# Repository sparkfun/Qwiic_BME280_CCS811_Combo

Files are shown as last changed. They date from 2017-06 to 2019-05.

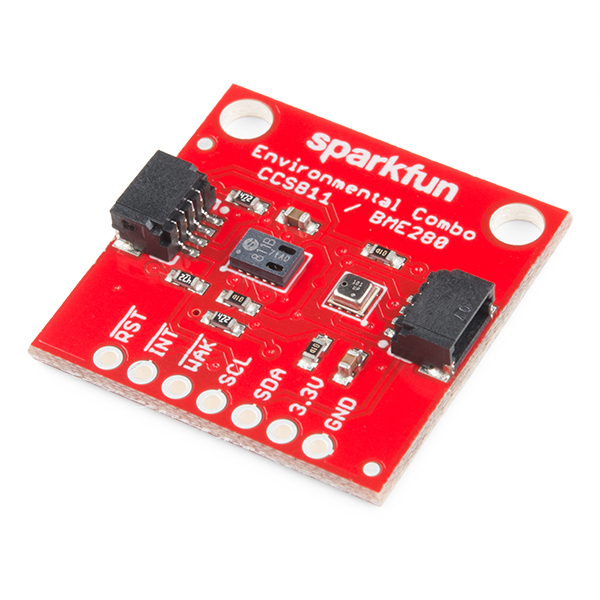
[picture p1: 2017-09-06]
Documentation/readme_picture.jpg

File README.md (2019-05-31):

SparkFun CCS811/BME280 Combo Board
========================================

Sparkfun CCS811/BME280 Combo Board

[*Sparkfun Environmental Combo Breakout CCS811/BME280 (SEN-14348)*](https://www.sparkfun.com/products/14348)

The SparkFun CCS811/BME280 Combo Breakout is perfect for sensing anything you may want to know about the air quality. This breakout will fine tune eCO<sub>2</sub> and tVOC readings from the CCS811 using humidity and temperature readings from the BME280. The breakout will also detect barometric pressure.

Repository Contents
-------------------

* **/Documentation** - Data sheets, additional product information
* **/Firmware** - Example code 
* **/Hardware** - Eagle design files (.brd, .sch)
* **/Libraries** - Libraries for use with the <CCS811/BME280>
* **/Production** - Production panel files (.brd)
* **/Software** - Related software for the <CCS811/BME280>

Documentation
--------------
* **[Library](https://github.com/sparkfun/SparkFun_CCS811_Arduino_Library/)** - <Arduino> library for the CCS811.
* **[Library](https://github.com/sparkfun/SparkFun_BME280_Arduino_Library/)** - <Arduino> library for the BME280.
* **[Hookup Guide](https://learn.sparkfun.com/tutorials/ccs811bme280-qwiic-environmental-combo-breakout-hookup-guide)** - Basic hookup guide for the CCS811/BME280.
* **[SparkFun Fritzing repo](https://github.com/sparkfun/Fritzing_Parts)** - Fritzing diagrams for SparkFun products.
* **[SparkFun 3D Model repo](https://github.com/sparkfun/3D_Models)** - 3D models of SparkFun products. 
* **[SparkFun Graphical Datasheets](https://github.com/sparkfun/Graphical_Datasheets)** -Graphical Datasheets for various SparkFun products.

Product Versions
----------------
* [SEN-14348](https://www.sparkfun.com/products/14348)- Breakout board for the CCS811 and BME 280 air quality sensors.

Version History
---------------
* [CCS811 - V 1.0.0](https://github.com/sparkfun/CCS811_Air_Quality_Breakout/tree/V_1.0.0) - Initial commit of Arduino compatible library for CCS811 
* [BME280 - V 1.0.0](https://github.com/sparkfun/SparkFun_BME280_Arduino_Library/tree/V_1.0.0) - Initial commit of Arduino compatible library for BME280
* [BME280 - V 1.1.0](https://github.com/sparkfun/SparkFun_BME280_Arduino_Library/tree/V_1.1.0) - Pulled request to add decimal precision to readFloatPressure() and readFloatHumidity().

License Information
-------------------

This product is _**open source**_! 

Please review the LICENSE.md file for license information. 

If you have any questions or concerns on licensing, please contact techsupport@sparkfun.com.

Distributed as-is; no warranty is given.

- Your friends at SparkFun.

_<COLLABORATION CREDIT>_

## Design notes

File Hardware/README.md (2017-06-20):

SparkFun <PRODUCT NAME> Design Files
=====================================

The .sch and .brd files hare are Eagle CAD schematic and PCB design files from SparkFun Electronics.
A freeware version of Eagle can be found [here](http://www.cadsoftusa.com/download-eagle/freeware/).

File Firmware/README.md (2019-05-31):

SparkFun CCS811/BME280 Qwiic Environmental Combo Breakout Firmware
===================================

* **Examples** - Arduino examples used in the Environmental Combo Hookup Guide

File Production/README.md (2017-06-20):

SparkFun <PRODUCT NAME> Production Files
=========================================

These are the production files SparkFun uses for printing PCBs.

License Information
-------------------
This product is open source! 

The hardware is released under [Creative Commons ShareAlike 4.0 International](https://creativecommons.org/licenses/by-sa/4.0/).

Please use, reuse, and modify these files as you see fit. Please maintain attribution to SparkFun Electronics and release anything derivative under the same license.

Distributed as-is; no warranty is given.

- Your friends at SparkFun.

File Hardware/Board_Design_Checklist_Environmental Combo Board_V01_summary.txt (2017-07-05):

1) Do all VCC connections use the VCC symbol (oriented upward)? [NO]
comment: 3.3V instead of VCC, should probably stay this way?

2) Do all testpoints have a separation of at least 0.1 inch (preferably placed on a 0.05 inch grid)? [n/a]
comment: no test points? I2C connectors for test

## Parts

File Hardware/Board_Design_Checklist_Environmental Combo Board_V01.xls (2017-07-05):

SECTION | CHECK | STATUS | DEPENDANCY | CORRECT ANSWER | USER | USER-ANSWER | COMMENT | WIKI_LINK
Macro | is_revision | 1
Macro | has_pth | 1
Macro | has_i2c | 1
Macro | has_SPI | 0
Macro | has_1x6_ftdi_header | 0
Macro | has_jumpers | 0
Macro | has_leds | 0
Macro | has_vreg | 0
Macro | has_QFN | 0
Macro | has_SS | 0
Macro | has_multi_sheet | 0
Macro | is_kit | 0
Macro | has_serial | 0
Macro | is_4layer | 0
Macro | has_milling | 0
Macro | has_switchorbutton | 0
General | Are the part libraries consistent with eagle github repo? |  |  | YES | andrew.england | YES
Schematic | Is the proper frame with CC attribution used? |  |  | YES | andrew.england | YES
Schematic | Are all schematic objects inside the frame? |  |  | YES | andrew.england | YES
Schematic | Is there a SparkFun Logo? |  |  | YES | andrew.england | YES
Schematic | Is there an OSHW logo? |  |  | YES | andrew.england | YES
Schematic | Is proper attribution given to the original designer? |  |  | YES | andrew.england | YES
Schematic | Is "Revised by: " and the reviser's name present? |  | 2 | YES | andrew.england | YES
Schematic | Are NET labels the correct FLAG type? |  |  | YES | andrew.england | YES
Schematic | Have all nets been drawn straight out from pin connections at least one grid space? |  |  | YES | andrew.england | YES
Schematic | Are all net lines 0.006 inch? |  |  | YES | andrew.england | YES
Schematic | Are there any 4-way junctions? |  |  | NO | andrew.england | NO
Schematic | Are junction dots used for all 3-wire connections? |  |  | YES | andrew.england | YES
Schematic | Are the fiducials in the lower right corner? |  |  | YES | andrew.england | YES
Schematic | Are the standoffs in the lower right corner? |  |  | YES | andrew.england | YES
Schematic | Are dashed grey lines ('info' eagle layer 97) used to clearly separate different areas? |  |  | YES | andrew.england | YES
Schematic | Is the version number correct? |  |  | YES | andrew.england | YES
Schematic | Is the version number included on all sheets? |  | 12 | YES | andrew.england | *n/a*
Schematic | Do all GND connections use the GND symbol (oriented downward)? |  |  | YES | andrew.england | YES
Schematic | Do all VCC connections use the VCC symbol (oriented upward)? |  |  | YES | andrew.england | NO | 3.3V instead of VCC, should probably stay this way?
Schematic | Is the VCC range clearly labeled? |  |  | YES | andrew.england | YES
Schematic | Are any jumpers labeled clearly by their function and possible settings? |  | 7 | YES | andrew.england | *n/a*
Schematic | Are any appropriate warnings (voltage conversion, sensitive I/O) labeled? |  |  | YES | andrew.england | YES
Schematic | Are any notes of two versions of the board in the schematic (3.3V regulator vs 5V regulator)? |  |  | YES | andrew.england | n/a
Schematic | Do any part names have '/.~' in them? (Multiple sheets) |  | 12 | NO | andrew.england | *n/a*
Schematic | Have you verified that the BOM in Sparkle is accurate (also checking for PROD_ID, NAME, VALUE, PREFIX)? |  |  | YES | andrew.england | YES
Schematic | Do any parts have unnecessary values (Eagle has autoset the package as the value)? |  |  | NO | andrew.england | NO
Schematic | Regarding the voltage regulator, is the input on the LEFT, and the output on the RIGHT? |  | 9 | YES | andrew.england | *n/a*
Schematic | Is the I2C address in the schematic? |  | 4 | YES | andrew.england | YES
Schematic | Is it the standard I2C pin order used (GND/VCC/SDA/CLK)? |  | 4 | YES | andrew.england | YES |  | http://wiki.internal.sparkfun.com/index.php?title=Eagle_Rules#Pin_Out.2FConnection_Orientation
Schematic | Is the I2C pull-up resistor isolation jumper present? |  | 4 | YES | andrew.england | YES |  | http://wiki.internal.sparkfun.com/index.php?title=Eagle_Rules#Component_Placement
Schematic | Is the SPI pull-up resistor for Chip Select present? |  | 5 | YES | andrew.england | *n/a* |  | http://wiki.internal.sparkfun.com/index.php?title=Eagle_Rules#Component_Placement
Schematic | Is the MISO tri-state buffer included? |  | 5 | YES | andrew.england | *n/a* |  | http://wiki.internal.sparkfun.com/index.php?title=Eagle_Rules#Component_Placement
Board | Are the inner layers on the correct eagle layers? (2 and 15) |  | 15 | YES | andrew.england | *n/a* |  | http://wiki.internal.sparkfun.com/index.php?title=Eagle_Rules#Board_Creation.2C_Outline
Board | Does your 4 layer board include '1' '2' '3' '4' in the copper of each layer? |  | 15 | YES | andrew.england | *n/a* |  | http://wiki.internal.sparkfun.com/index.php?title=Eagle_Rules#Board_Creation.2C_Outline
Board | Is the bottom left corner board dimensions at 0,0? |  |  | YES | andrew.england | YES |  | http://wiki.internal.sparkfun.com/index.php?title=Eagle_Rules#Board_Creation.2C_Outline
Board | Is the board dimension outline correct thickness? (0.008 inch) |  |  | YES | andrew.england | YES |  | http://wiki.internal.sparkfun.com/index.php?title=Eagle_Rules#Board_Creation.2C_Outline
Board | If this requires very precise dimensions (e.g. USB stick), did you consider GP's tolerances? (dimension=5mils, Vscore=10mils) |  |  |  | andrew.england | YES |  | http://wiki.internal.sparkfun.com/index.php?title=Eagle_Rules#Fab_house_Tolerances
Board | Are 0.1 inch headers lined up on 0.1 inch grid? |  |  | YES | andrew.england | YES |  | http://wiki.internal.sparkfun.com/index.php?title=Eagle_Rules#Board_Creation.2C_Outline
Board | Are opposing 0.1 inch headers spaced to fit into a breadboard? |  |  | YES | andrew.england | n/a |  | http://wiki.internal.sparkfun.com/index.php?title=Eagle_Rules#Board_Creation.2C_Outline
Board | Do all testpoints have a separation of at least 0.1 inch (preferably placed on a 0.05 inch grid)? |  |  | YES | andrew.england | n/a | no test points? I2C connectors for test | http://wiki.internal.sparkfun.com/index.php?title=Eagle_Rules#Board_Creation.2C_Outline
Board | Does the board have standoffs? |  |  | YES | andrew.england | YES |  | http://wiki.internal.sparkfun.com/index.php?title=Eagle_Rules#Board_Creation.2C_Outline
Board | Can standoffs/screws be used clear of other parts? |  |  | YES | andrew.england | YES |  | http://wiki.internal.sparkfun.com/index.php?title=Eagle_Rules#Board_Creation.2C_Outline
Board | Is the FTDI connector accessible (do neighboring parts allow enough space to clear each side)? |  | 6 | YES | andrew.england | *n/a* |  | http://wiki.internal.sparkfun.com/index.php?title=Eagle_Rules#Pin_Out.2FConnection_Orientation
Board | Is the FTDI connector oriented so the FTDI breakout can be slid on properly (IC side up, header side down)? |  | 6 | YES | andrew.england | *n/a* |  | http://wiki.internal.sparkfun.com/index.php?title=Eagle_Rules#Pin_Out.2FConnection_Orientation
Board | Are vias tented correctly? |  |  | YES | andrew.england | YES |  | http://wiki.internal.sparkfun.com/index.php?title=Eagle_Rules
Board | If possible, are all overhanging parts on the same edge of the board (this helps with panelization)? |  |  | YES | andrew.england | YES |  | http://wiki.internal.sparkfun.com/index.php?title=Eagle_Rules#Pin_Out.2FConnection_Orientation
Board | Does this board adhere to the standard manufacturing process? (Kitting time, glue curing, humidor time, etc.) |  |  | YES | andrew.england | YES
Board | Are any vias intended to be used as PTH headers (they shouldn't be)? |  |  | NO | andrew.england | NO |  | http://wiki.internal.sparkfun.com/index.php?title=Eagle_Rules
Board | Is the LED color standard followed? (red for power, blue for STAT, green for TX, yellow for RX) |  | 8 | YES | andrew.england | *n/a* |  | http://wiki.internal.sparkfun.com/index.php?title=Eagle_Rules#Component_Placement
Board | Are all PTH parts selective solder compatible? (same side, plenty of clearance around pins) |  | 11 | YES | andrew.england | *n/a* |  | http://wiki.internal.sparkfun.com/index.php?title=Eagle_Rules#Pin_Out.2FConnection_Orientation
Board | As best as possible, do all SMD pads have only 1 trace entering the pad? |  |  | YES | andrew.england | YES |  | http://wiki.internal.sparkfun.com/index.php?title=Eagle_Rules#PCB_Layout
Board | Are there any natural bridges on SMT components? |  |  | NO | andrew.england | YES |  | http://wiki.internal.sparkfun.com/index.php?title=Eagle_Rules#PCB_Layout
Board | Do V-Scored edges have a 50 mil border free of pads and parts (to prevent cracking on separation)? |  |  | YES | andrew.england | n/a
Board | Is the direction of TX/RX serial connections correct? |  | 14 | YES | andrew.england | *n/a*
Board | Are the TX/RX pins of the FTDI properly connected? |  | 6 | YES | andrew.england | *n/a*
Board | Is trace routing up to spec? (to/from center-points, straight lines, 45 angles, 'T' intersections, no right angles or acid traps) |  |  | YES | andrew.england | YES |  | http://wiki.internal.sparkfun.com/index.php?title=Eagle_Rules#PCB_Layout
Board | For thermal considerations, are traces routed away from the component, with symmetrical routing? |  | 10 | YES | andrew.england | *n/a*
Board | Do all footprints pass 1:1 check? (Applies mostly to new components) |  |  | YES | andrew.england | YES
Board | Are all QFN components with 6 or more leads 75 percent pasted on lead pads? (May be contended depending on performance) |  | 10 | YES | andrew.england | *n/a* |  | http://wiki.internal.sparkfun.com/index.php?title=Eagle_Rules#Footprints.2FPackages
Board | Are center pad cream apertures properly reduced? (50-75% paste is good) |  | 10 | YES | andrew.england | *n/a* |  | http://wiki.internal.sparkfun.com/index.php?title=Eagle_Rules#Footprints.2FPackages
Board | Is there solder mask between pads on of 11 mil separation and greater? |  |  | YES | andrew.england | YES |  | http://wiki.internal.sparkfun.com/index.php?title=Eagle_Rules#Fab_house_Tolerances
Board | Is there a correct version number in the copper (aligned properly with the edge of the PCB)? |  |  | YES | andrew.england | YES
Board | Are there fiducials on both the TOP and BOTTOM of the board? |  |  | YES | andrew.england | YES
Board | Does it pass DRC with top/bottom keepout layers on? |  |  | YES | andrew.england | YES
Board | If there are any DRC errors, have they all been approved? |  |  | YES | andrew.england | YES
Board | Are there airwires after ratsnest? |  |  | NO | andrew.england | NO
Board | Are all KIT PTH parts on the correct side with correct masking (e.g. the TSTOP or BSTOP expose the correct side) |  | 13 | YES | andrew.england | *n/a*
Documentation | Is there a note for a 4-layer board (on tDOCU)? |  | 15 | YES | andrew.england | *n/a*
Documentation | Do all packages have NAME and VALUE? |  |  | YES | andrew.england | YES
Documentation | Is there a note for a board thickness other than 0.63 inch? |  |  |  | andrew.england | NO
Documentation | Are measurements included for outer dimension and standoffs (Eagle layer 47)? |  |  | YES | andrew.england | YES
Documentation | Are the board dimensions on 0.05 inch or 0.01 inch grid? |  |  | YES | andrew.england | YES
Documentation | Are routed-out areas labeled 'ROUTE OUT' (on dimension)? |  | 16 | YES | andrew.england | *n/a*
Documentation | Is the CC/Design By included in tDocu? |  |  | YES | andrew.england | YES
Documentation | Is the designer name included in tDocu? |  |  | YES | andrew.england | YES
Documentation | Is 'Revised by:' and 'Revisor Name' included in tDocu? |  | 2 | YES | andrew.england | YES
Silkscreen/Labeling | Is the name of the board on the board? |  |  | YES | andrew.england | YES |  | http://wiki.internal.sparkfun.com/index.php?title=Eagle_Rules#PCB_Silk
Silkscreen/Labeling | Do all footprints have 0.008 inch silk footprint? |  |  | YES
Silkscreen/Labeling | Are all LEDs labeled with their purpose? |  | 8 | YES
Silkscreen/Labeling | Are all PTHs (aka connectors) clearly labeled with their purpose on both sides of the board? |  |  | YES | andrew.england | YES
Silkscreen/Labeling | Are battery terminals labeled +/- correctly? |  |  | YES | andrew.england | YES
Silkscreen/Labeling | Are all jumpers labeled? |  | 7 | YES | andrew.england | *n/a*
Silkscreen/Labeling | If it is a 3-way jumper, is there a label on each side of the jumper? |  | 7 | YES | andrew.england | *n/a*
Silkscreen/Labeling | Are all switches/buttons labeled properly? |  | 17 | YES | andrew.england | *n/a*
Silkscreen/Labeling | Are active low pins labeled clearly? |  |  | YES | andrew.england | YES
Silkscreen/Labeling | Are all labels lined up properly? |  |  | YES | andrew.england | YES
Silkscreen/Labeling | Is all text at least 0.032 inch, 15 percent radio, and vector? |  |  | YES | andrew.england | YES
Silkscreen/Labeling | Does the FTDI connector have BLK/GRN labeled correctly? |  | 6 | YES | andrew.england | *n/a*
Silkscreen/Labeling | Do all components have polarity or pin 1 labeled? |  |  | YES | andrew.england | YES
Silkscreen/Labeling | Is the polarity label outside of the package for visibility after part population? |  |  | YES | andrew.england | YES
Silkscreen/Labeling | Are there check labels for different versions of the board (3.3V vs 5V)? |  |  | YES | andrew.england | n/a
Silkscreen/Labeling | Is the SparkFun Logo on the board? |  |  | YES | andrew.england | YES
Silkscreen/Labeling | Is the OSHW logo on the board? |  |  | YES | andrew.england | YES
Silkscreen/Labeling | Is any silkscreen overlaid on vias? |  |  | NO | andrew.england | YES
Silkscreen/Labeling | Is there a URL for any kits or unique boards? |  |  |  | andrew.england | NO
Special | Are dimension lines properly spaced for V-scoring (lines on a 0.020” center-to-center spacing)? |  |  |  | andrew.england | n/a
Special | On white solder mask pcbs, is there any solder mask between leads on large SMT components? |  |  |  | andrew.england | n/a
Special | Are axes labeled correctly? |  |  |  | andrew.england | n/a
Special | Are there warning labels for high voltage areas? |  |  |  | andrew.england | n/a
END | Thanks for flying with us. Have a great day!! |  |  |  | andrew.england | n/a

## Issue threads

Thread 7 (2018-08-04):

I2C_Error with Wemos D1 R2

Coderkido, 2018-08-04:
Hi,
Using libraries was working with an Uno, using the module on Wemos is returning I2C Errors for the CCS and same for BME280.

Both devices are discovered with an I2C Scan.

https://gist.github.com/Coderkido/1b58b96edec79937f611ece7d0b867c8

Is a gist of what I'm doing.

Coderkido, 2018-08-04:
I2C Scan SOMETIMES find the devices.

Otherwise returns:

`Unknow error at address 0x69
Unknow error at addr
Soft WDT reset

ctx: cont
sp: 3ffef7a0 end: 3ffef9f0 offset: 01b0

>>>stack>>>
3ffef950:  feefeffe 00000001 3ffe88e6 40202d54
3ffef960:  00000000 00000014 3ffe88c2 40202d54
3ffef970:  0000006a 00000002 3ffee99c 3ffee748
3ffef980:  00000000 0000006a 3ffee99c 402028b5
3ffef990:  3ffe88ae 0000006a 3ffee759 402026a8
3ffef9a0:  3ffe8870 00000001 3ffee99c 402028c8
3ffef9b0:  00002580 00000069 3ffee99c 40202480
3ffef9c0:  feefeffe 00000000 3ffee99c 3ffee9c0
3ffef9d0:  3fffdad0 00000000 3ffee9b8 40202b74
3ffef9e0:  feefeffe feefeffe 3ffee9d0 40100108
<<<stack<<<
⸮⸮⸮⸮(⸮⸮
y⸮
I2C Scanner
Scanning...
`

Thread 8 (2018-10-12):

code replicates error in vendor documentation

pabigot, 2018-10-12:
Around [here](https://github.com/sparkfun/Qwiic_BME280_CCS811_Combo/blob/3e43b3289bce05ccb271034105f0ce0e1a6ca11d/Libraries/CCS811/src/SparkFunCCS811.cpp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) the code for configuring the CCS811 ENV_DATA values faithfully represents the instructions in the [CCS811 Programming guide](https://ams.com/documents/20143/36005/CCS811_AN000369_2-00.pdf/25d0db9a-92b9-fa7f-362c-a7a4d1e292be) section 16, being:
```
i2c_buff[0] = ((RH % 1000) / 100) > 7 ? (RH/1000 + 1)<<1 : (RH/1000)<<1;
i2c_buff[1] = 0;
if(((RH % 1000) / 100) > 2 && (((RH % 1000) / 100) < 8)) {
  i2c_buff[0] |= 1;
}
```
The demonstration code is wrong, as it results in storing a value that is one unit too large when the fractional part is strictly between 0.7 and 0.8.  In that case the whole value is incremented and the half-value is added, applying the half-round operation twice.

I don't use this library, but found this while trying to figure out why writing `ENV_DATA` doesn't work on my board (the I2C read of address 0x05 sets `READ_REG_INVALID` in `ERROR_ID`), and figured somebody might find this useful.

nseidle, 2018-10-12:
I think I get what you're saying.

Let's run 42.745 through the code.

    envData[0] = ((rH % 1000) / 100) > 7 ? (rH / 1000 + 1) << 1 : (rH / 1000) << 1;

This puts (42<<1) in envData[0]. Then

    if (((rH % 1000) / 100) > 2 && (((rH % 1000) / 100) < 8))
        envData[0] |= 1; //Set 9th bit of fractional to indicate 0.5%

This puts the 0.5 into bit 0. So the outcome is 42.5%. Looks good.

Let's run 42.856 through.

    envData[0] = ((rH % 1000) / 100) > 7 ? (rH / 1000 + 1) << 1 : (rH / 1000) << 1;

This puts (43<<1) in envData[0]. Then

    if (((rH % 1000) / 100) > 2 && (((rH % 1000) / 100) < 8))
        envData[0] |= 1; //Set 9th bit of fractional to indicate 0.5%

This puts the 0.5 into bit 0. So the outcome is 43.5%. That's too much.

So I think the solution is:

    envData[1] = 0; //CCS811 only supports increments of 0.5 so bits 7-0 will always be zero

    //Split value into 7-bit integer and 9-bit fractional
    if( (rH % 1000) / 100 > 7)
    {
      envData[0] = (rH / 1000 + 1) << 1; //Increase 42.756 to 43.0
    }
    else
    {
      envData[0] = (rH / 1000) << 1; //Store 42
      if ( (rH % 1000) / 100 > 2)
        envData[0] |= 1; //Set 9th bit of fractional to indicate 0.5% - 42.5%
    }

pabigot, 2018-10-12:
Yeah, you could do something like that.  Or just rely on integer truncation and do:
```
envData[0] = (rH + 250) / 500;
```
which rounds to the nearest half unit.

nseidle, 2018-10-12:
Much sneakier. Thanks - updating lib.

pabigot, 2018-10-12:
You're welcome.

If anybody else gets here because attempting to read the `ENV_DATA` register fails, my conclusion is that the register is not readable: it fails with both app firmware 1.1.0 (which was on the Sparkfun board I got long ago), and with 2.0.0.  Which is pretty annoying, since I'd like to know whether the power-on state has sane defaults (see NordicSemiconductor/Nordic-Thingy52-FW#21 for background).

Also, initial experience with 2.0.0 appears to fix a variety of issues with the status, and maybe baseline maintenance.

hmhalvorsen, 2018-12-17:
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

I am not sure if this is correct. ((42856 mod 1000) / 100) = 8.56, which is not less than 8. Surely we wouldn't set the 9th bit here?

hmhalvorsen, 2018-12-17:
Yes, that makes sense. Thank you for clarifying this matter.

fbraswell, 2019-06-18:
Why to go all the trouble of the code in the data sheet, which tries to keep the 8 bits of fraction zero? The direct way to populate the two %RH registers is to multiply the RH value by 512, convert the value to an int and split it in two. Here's the code in the Squirrel language for the Electric Imp processor:

        // The 16 bit %RH register is composed of a 7 bit integer portion and 9 bit
        // fractional portion. Multiplying the %RH by 512 effectively populates the
        // integer and fractional portion.
        local h = hval * 512;
        // Next, split the two bytes of the integer apart for sending to the ENV_DATA registers
        local h_hi = h.tointeger() >> 8; // get upper 8 bits
        local h_lo = h.tointeger() & 0x00FF; // grab lower 8 bits

The temperature calculation adds the 25 degree offset:

        // First, convert the tempF to tempC
        local tvalC = (tvalF - 32.0) * 5.0 / 9.0;
        // In this case, there is an offset of 25 deg C. This means that if the 2 registers are 0
        // then the temperature is -25 deg C
        // For the computation, add the offset of 25 and multiply by 512, as we did with the %RH above
        local t = (tvalC + 25.0) * 512;
        // Split the integer into two parts for sending the the ENV_DATA registers
        local t_hi = t.tointeger() >> 8; // get upper 8 bits
        local t_lo = h.tointeger() & 0x00FF; // grab lower 8 bits

532910, 2019-07-20:
[CCS811 datasheet](https://ams.com/documents/20143/36005/CCS811_DS000459_7-00.pdf/3cfdaea5-b602-fe28-1a14-18776b61a35a) says:
> Temperature / Humidity is stored as an unsigned 16 bits in 1/512

Could you explain, why

> bits 7-0 will always be zero

?

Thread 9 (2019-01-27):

Example for combined reading on Raspberry Pi?

syr, 2019-01-27:
I'm a bloody beginner. So it would be helpful to see in an example
how to do combined readings with python which can be executed on a raspberry pi. :)
Any chance?

nseidle, 2019-01-30:
We'd welcome a PR on either of the sensor libraries ([CCS811](https://github.com/sparkfun/SparkFun_CCS811_Arduino_Library/) or [BME280](https://github.com/sparkfun/SparkFun_BME280_Arduino_Library/)) from anyone who want to contribute but most of our support is for Arduino instead of RPi/python.

Closed 2019-01-30.

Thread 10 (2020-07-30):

Examples won't compile

cmfrancis, 2020-07-30:
Last line of the error received is:
variable or field 'printDriverError' declared void

crampaldo, 2020-09-18:
I am having the same error

JustMakeStuff-tech, 2020-10-09:
I am having that same error as well

JustMakeStuff-tech, 2020-10-09:
I just proposed some changes where the "variable or field 'printDriverError' declared void" error is fixed

JustMakeStuff-tech, 2023-05-11:
See [https://github.com/sparkfun/Qwiic_BME280_CCS811_Combo/commit/b0c013b651c99ae166d396f3a4776d240a9861f1](this).

JialongWang1201, 2023-05-11:
> See [this](https://github.com/sparkfun/Qwiic_BME280_CCS811_Combo/commit/b0c013b651c99ae166d396f3a4776d240a9861f1).

/private/var/folders/rj/1zgtr70j3lb03hztfp7t7tlc0000gn/T/.arduinoIDE-unsaved2023411-27445-w42zu.6hw5w/sketch_may11a/sketch_may11a.ino:22:12: error: stray '@' in program
 Expand All @@ -67,11 +67,11 @@ void setup()
            ^
/private/var/folders/rj/1zgtr70j3lb03hztfp7t7tlc0000gn/T/.arduinoIDE-unsaved2023411-27445-w42zu.6hw5w/sketch_may11a/sketch_may11a.ino:22:13: error: stray '@' in program
 Expand All @@ -67,11 +67,11 @@ void setup()
             ^
/private/var/folders/rj/1zgtr70j3lb03hztfp7t7tlc0000gn/T/.arduinoIDE-unsaved2023411-27445-w42zu.6hw5w/sketch_may11a/sketch_may11a.ino:22:29: error: stray '@' in program
 Expand All @@ -67,11 +67,11 @@ void setup()
                             ^
/private/var/folders/rj/1zgtr70j3lb03hztfp7t7tlc0000gn/T/.arduinoIDE-unsaved2023411-27445-w42zu.6hw5w/sketch_may11a/sketch_may11a.ino:22:30: error: stray '@' in program
 Expand All @@ -67,11 +67,11 @@ void setup()
                              ^
/private/var/folders/rj/1zgtr70j3lb03hztfp7t7tlc0000gn/T/.arduinoIDE-unsaved2023411-27445-w42zu.6hw5w/sketch_may11a/sketch_may11a.ino:34:12: error: stray '@' in program
 Expand All @@ -90,18 +90,18 @@ void loop()
            ^
/private/var/folders/rj/1zgtr70j3lb03hztfp7t7tlc0000gn/T/.arduinoIDE-unsaved2023411-27445-w42zu.6hw5w/sketch_may11a/sketch_may11a.ino:34:13: error: stray '@' in program
 Expand All @@ -90,18 +90,18 @@ void loop()
             ^
/private/var/folders/rj/1zgtr70j3lb03hztfp7t7tlc0000gn/T/.arduinoIDE-unsaved2023411-27445-w42zu.6hw5w/sketch_may11a/sketch_may11a.ino:34:29: error: stray '@' in program
 Expand All @@ -90,18 +90,18 @@ void loop()
                             ^
/private/var/folders/rj/1zgtr70j3lb03hztfp7t7tlc0000gn/T/.arduinoIDE-unsaved2023411-27445-w42zu.6hw5w/sketch_may11a/sketch_may11a.ino:34:30: error: stray '@' in program
 Expand All @@ -90,18 +90,18 @@ void loop()
                              ^
/private/var/folders/rj/1zgtr70j3lb03hztfp7t7tlc0000gn/T/.arduinoIDE-unsaved2023411-27445-w42zu.6hw5w/sketch_may11a/sketch_may11a.ino:53:12: error: stray '@' in program
 Expand All @@ -110,70 +110,71 @@ void loop()
            ^
/private/var/folders/rj/1zgtr70j3lb03hztfp7t7tlc0000gn/T/.arduinoIDE-unsaved2023411-27445-w42zu.6hw5w/sketch_may11a/sketch_may11a.ino:53:13: error: stray '@' in program
 Expand All @@ -110,70 +110,71 @@ void loop()
             ^
/private/var/folders/rj/1zgtr70j3lb03hztfp7t7tlc0000gn/T/.arduinoIDE-unsaved2023411-27445-w42zu.6hw5w/sketch_may11a/sketch_may11a.ino:53:31: error: stray '@' in program
 Expand All @@ -110,70 +110,71 @@ void loop()
                               ^
/private/var/folders/rj/1zgtr70j3lb03hztfp7t7tlc0000gn/T/.arduinoIDE-unsaved2023411-27445-w42zu.6hw5w/sketch_may11a/sketch_may11a.ino:53:32: error: stray '@' in program
 Expand All @@ -110,70 +110,71 @@ void loop()
                                ^
/private/var/folders/rj/1zgtr70j3lb03hztfp7t7tlc0000gn/T/.arduinoIDE-unsaved2023411-27445-w42zu.6hw5w/sketch_may11a/sketch_may11a.ino:101:24: error: variable or field 'printDriverError' declared void
  void printDriverError( CCS811Core::CCS811_Status_e errorCode )
                        ^~~~~~~~~~
/private/var/folders/rj/1zgtr70j3lb03hztfp7t7tlc0000gn/T/.arduinoIDE-unsaved2023411-27445-w42zu.6hw5w/sketch_may11a/sketch_may11a.ino:101:24: error: 'CCS811Core' has not been declared
/private/var/folders/rj/1zgtr70j3lb03hztfp7t7tlc0000gn/T/.arduinoIDE-unsaved2023411-27445-w42zu.6hw5w/sketch_may11a/sketch_may11a.ino: In function 'void setup()':
/private/var/folders/rj/1zgtr70j3lb03hztfp7t7tlc0000gn/T/.arduinoIDE-unsaved2023411-27445-w42zu.6hw5w/sketch_may11a/sketch_may11a.ino:7:4: error: 'Wire' was not declared in this scope
    Wire.begin();//initialize I2C bus
    ^~~~
/private/var/folders/rj/1zgtr70j3lb03hztfp7t7tlc0000gn/T/.arduinoIDE-unsaved2023411-27445-w42zu.6hw5w/sketch_may11a/sketch_may11a.ino:10:4: error: 'CCS811Core' has not been declared
    CCS811Core::CCS811_Status_e returnCode = myCCS811.beginWithStatus ();
    ^~~~~~~~~~
/private/var/folders/rj/1zgtr70j3lb03hztfp7t7tlc0000gn/T/.arduinoIDE-unsaved2023411-27445-w42zu.6hw5w/sketch_may11a/sketch_may11a.ino:11:8: error: 'returnCode' was not declared in this scope
    if (returnCode != CCS811Core::CCS811_Stat_SUCCESS)
        ^~~~~~~~~~
/private/var/folders/rj/1zgtr70j3lb03hztfp7t7tlc0000gn/T/.arduinoIDE-unsaved2023411-27445-w42zu.6hw5w/sketch_may11a/sketch_may11a.ino:11:22: error: 'CCS811Core' has not been declared
    if (returnCode != CCS811Core::CCS811_Stat_SUCCESS)
                      ^~~~~~~~~~
/private/var/folders/rj/1zgtr70j3lb03hztfp7t7tlc0000gn/T/.arduinoIDE-unsaved2023411-27445-w42zu.6hw5w/sketch_may11a/sketch_may11a.ino:14:6: error: 'printDriverError' was not declared in this scope
      printDriverError(returnCode);
      ^~~~~~~~~~~~~~~~
/private/var/folders/rj/1zgtr70j3lb03hztfp7t7tlc0000gn/T/.arduinoIDE-unsaved2023411-27445-w42zu.6hw5w/sketch_may11a/sketch_may11a.ino:22:1: error: 'Expand' was not declared in this scope
 Expand All @@ -67,11 +67,11 @@ void setup()
 ^~~~~~
/private/var/folders/rj/1zgtr70j3lb03hztfp7t7tlc0000gn/T/.arduinoIDE-unsaved2023411-27445-w42zu.6hw5w/sketch_may11a/sketch_may11a.ino:22:1: note: suggested alternative: 'srand'
 Expand All @@ -67,11 +67,11 @@ void setup()
 ^~~~~~
 srand
/private/var/folders/rj/1zgtr70j3lb03hztfp7t7tlc0000gn/T/.arduinoIDE-unsaved2023411-27445-w42zu.6hw5w/sketch_may11a/sketch_may11a.ino:24:8: error: 'id' was not declared in this scope
    if (id != 0x60)
        ^~
/private/var/folders/rj/1zgtr70j3lb03hztfp7t7tlc0000gn/T/.arduinoIDE-unsaved2023411-27445-w42zu.6hw5w/sketch_may11a/sketch_may11a.ino:34:8: error: expected ';' before 'All'
 Expand All @@ -90,18 +90,18 @@ void loop()
        ^~~
/private/var/folders/rj/1zgtr70j3lb03hztfp7t7tlc0000gn/T/.arduinoIDE-unsaved2023411-27445-w42zu.6hw5w/sketch_may11a/sketch_may11a.ino:36:23: error: 'myBME280' was not declared in this scope
      float BMEhumid = myBME280.readFloatHumidity();
                       ^~~~~~~~
/private/var/folders/rj/1zgtr70j3lb03hztfp7t7tlc0000gn/T/.arduinoIDE-unsaved2023411-27445-w42zu.6hw5w/sketch_may11a/sketch_may11a.ino:39:22: error: 'BMEtempC' was not declared in this scope
      SerialUSB.print(BMEtempC);
                      ^~~~~~~~
/private/var/folders/rj/1zgtr70j3lb03hztfp7t7tlc0000gn/T/.arduinoIDE-unsaved2023411-27445-w42zu.6hw5w/sketch_may11a/sketch_may11a.ino:39:22: note: suggested alternative: 'BMEhumid'
      SerialUSB.print(BMEtempC);
                      ^~~~~~~~
                      BMEhumid
/private/var/folders/rj/1zgtr70j3lb03hztfp7t7tlc0000gn/T/.arduinoIDE-unsaved2023411-27445-w42zu.6hw5w/sketch_may11a/sketch_may11a.ino:45:6: error: 'myCCS811' was not declared in this scope
      myCCS811.setEnvironmentalData(BMEhumid, BMEtempC);
      ^~~~~~~~
/private/var/folders/rj/1zgtr70j3lb03hztfp7t7tlc0000gn/T/.arduinoIDE-unsaved2023411-27445-w42zu.6hw5w/sketch_may11a/sketch_may11a.ino: At global scope:
/private/var/folders/rj/1zgtr70j3lb03hztfp7t7tlc0000gn/T/.arduinoIDE-unsaved2023411-27445-w42zu.6hw5w/sketch_may11a/sketch_may11a.ino:47:4: error: expected unqualified-id before 'else'
    else if (myCCS811.checkForStatusError())
    ^~~~
/private/var/folders/rj/1zgtr70j3lb03hztfp7t7tlc0000gn/T/.arduinoIDE-unsaved2023411-27445-w42zu.6hw5w/sketch_may11a/sketch_may11a.ino:52:9: error: expected constructor, destructor, or type conversion before '(' token
    delay(2000); //Wait for next reading
         ^
/private/var/folders/rj/1zgtr70j3lb03hztfp7t7tlc0000gn/T/.arduinoIDE-unsaved2023411-27445-w42zu.6hw5w/sketch_may11a/sketch_may11a.ino:53:1: error: 'Expand' does not name a type; did you mean 'srand'?
 Expand All @@ -110,70 +110,71 @@ void loop()
 ^~~~~~
 srand
/private/var/folders/rj/1zgtr70j3lb03hztfp7t7tlc0000gn/T/.arduinoIDE-unsaved2023411-27445-w42zu.6hw5w/sketch_may11a/sketch_may11a.ino:101:25: error: variable or field 'printDriverError' declared void
  void printDriverError( CCS811Core::CCS811_Status_e errorCode )
                         ^~~~~~~~~~
/private/var/folders/rj/1zgtr70j3lb03hztfp7t7tlc0000gn/T/.arduinoIDE-unsaved2023411-27445-w42zu.6hw5w/sketch_may11a/sketch_may11a.ino:101:25: error: 'CCS811Core' has not been declared

exit status 1

Compilation error: stray '@' in program

JialongWang1201, 2023-05-11:
> See [this](https://github.com/sparkfun/Qwiic_BME280_CCS811_Combo/commit/b0c013b651c99ae166d396f3a4776d240a9861f1).

but I got the new bug

JustMakeStuff-tech, 2023-05-11:
Can I see your code?

JialongWang1201, 2023-05-11:
> Can I see your code?

void setup()
 {
   SerialUSB.begin(9600);
   SerialUSB.println();
   SerialUSB.println("Apply BME280 data to CCS811 for compensation.");

   Wire.begin();//initialize I2C bus

   //This begins the CCS811 sensor and prints error status of .begin()
   CCS811Core::CCS811_Status_e returnCode = myCCS811.beginWithStatus ();
   if (returnCode != CCS811Core::CCS811_Stat_SUCCESS)
   {
     SerialUSB.println("Problem with CCS811");
     printDriverError(returnCode);
   }
   else
   {
     SerialUSB.println("CCS811 online");
   }

Expand All	@@ -67,11 +67,11 @@ void setup()
   byte id = myBME280.begin(); //Returns ID of 0x60 if successful
   if (id != 0x60)
   {
     SerialUSB.println("Problem with BME280");
   }
   else
   {
     SerialUSB.println("BME280 online");
   }

Expand All	@@ -90,18 +90,18 @@ void loop()
     float BMEtempC = myBME280.readTempC();
     float BMEhumid = myBME280.readFloatHumidity();

     SerialUSB.print("Applying new values (deg C, %): ");
     SerialUSB.print(BMEtempC);
     SerialUSB.print(",");
     SerialUSB.println(BMEhumid);
     SerialUSB.println();

     //This sends the temperature data to the CCS811
     myCCS811.setEnvironmentalData(BMEhumid, BMEtempC);
   }
   else if (myCCS811.checkForStatusError())
   {
     SerialUSB.println(myCCS811.getErrorRegister()); //Prints whatever CSS811 error flags are detected
   }

   delay(2000); //Wait for next reading
Expand All	@@ -110,70 +110,71 @@ void loop()
 //---------------------------------------------------------------
 void printData()
 {
   SerialUSB.print(" CO2[");
   SerialUSB.print(myCCS811.getCO2());
   SerialUSB.print("]ppm");

   SerialUSB.print(" TVOC[");
   SerialUSB.print(myCCS811.getTVOC());
   SerialUSB.print("]ppb");

   SerialUSB.print(" temp[");
   SerialUSB.print(myBME280.readTempC(), 1);
   SerialUSB.print("]C");

   //SerialUSB.print(" temp[");
   //SerialUSB.print(myBME280.readTempF(), 1);
   //SerialUSB.print("]F");

   SerialUSB.print(" pressure[");
   SerialUSB.print(myBME280.readFloatPressure(), 2);
   SerialUSB.print("]Pa");

   //SerialUSB.print(" pressure[");
   //SerialUSB.print((myBME280.readFloatPressure() * 0.0002953), 2);
   //SerialUSB.print("]InHg");
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
JialongWang1201, 2023-05-15:
> You just copied the page including buttons and labels that were not part of the code. You have to click the three dots, then click view file, then copy that. The link I sent previously is just showing the changes I made. If you want to copy the code directly, you can do so [here](https://github.com/sparkfun/Qwiic_BME280_CCS811_Combo/blob/b0c013b651c99ae166d396f3a4776d240a9861f1/Firmware/Example2-CombinedReading/Example2-CombinedReading.ino).

Could you help for this bug? i still can't fix it

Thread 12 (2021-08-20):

Qwiic_BME280_CCS811_Combo for python?

wolli1234, 2021-08-20:
Hello,

I'm trying to read BME280 humidity and temperature data to integrate it into CO2 calculation in the CCS811 sensor. I can run the Qwiic_CCS811_Py module and Qwiic_BME280_Py  module separately but I'm not getting how to send the data from one sensor to the other.

Can you give me a hint how to accomplish that in python? Is there a Qwiic_BME280_CCS811_Combo module for python?

Best regards,
Wolli

santaimpersonator, 2021-09-01:
Please refer to the [API documentation CCS811 Python package](https://qwiic-ccs811-py.readthedocs.io/en/latest/apiref.html#qwiic_ccs811.QwiicCcs811.set_environmental_data)

Since this issue has nothing to do with the hardware, I am transferring this issue to the GitHub repository for the CCS811 Python package. I am also closing the issue since it is addressed in the documentation (linked above).

Closed 2021-09-01.

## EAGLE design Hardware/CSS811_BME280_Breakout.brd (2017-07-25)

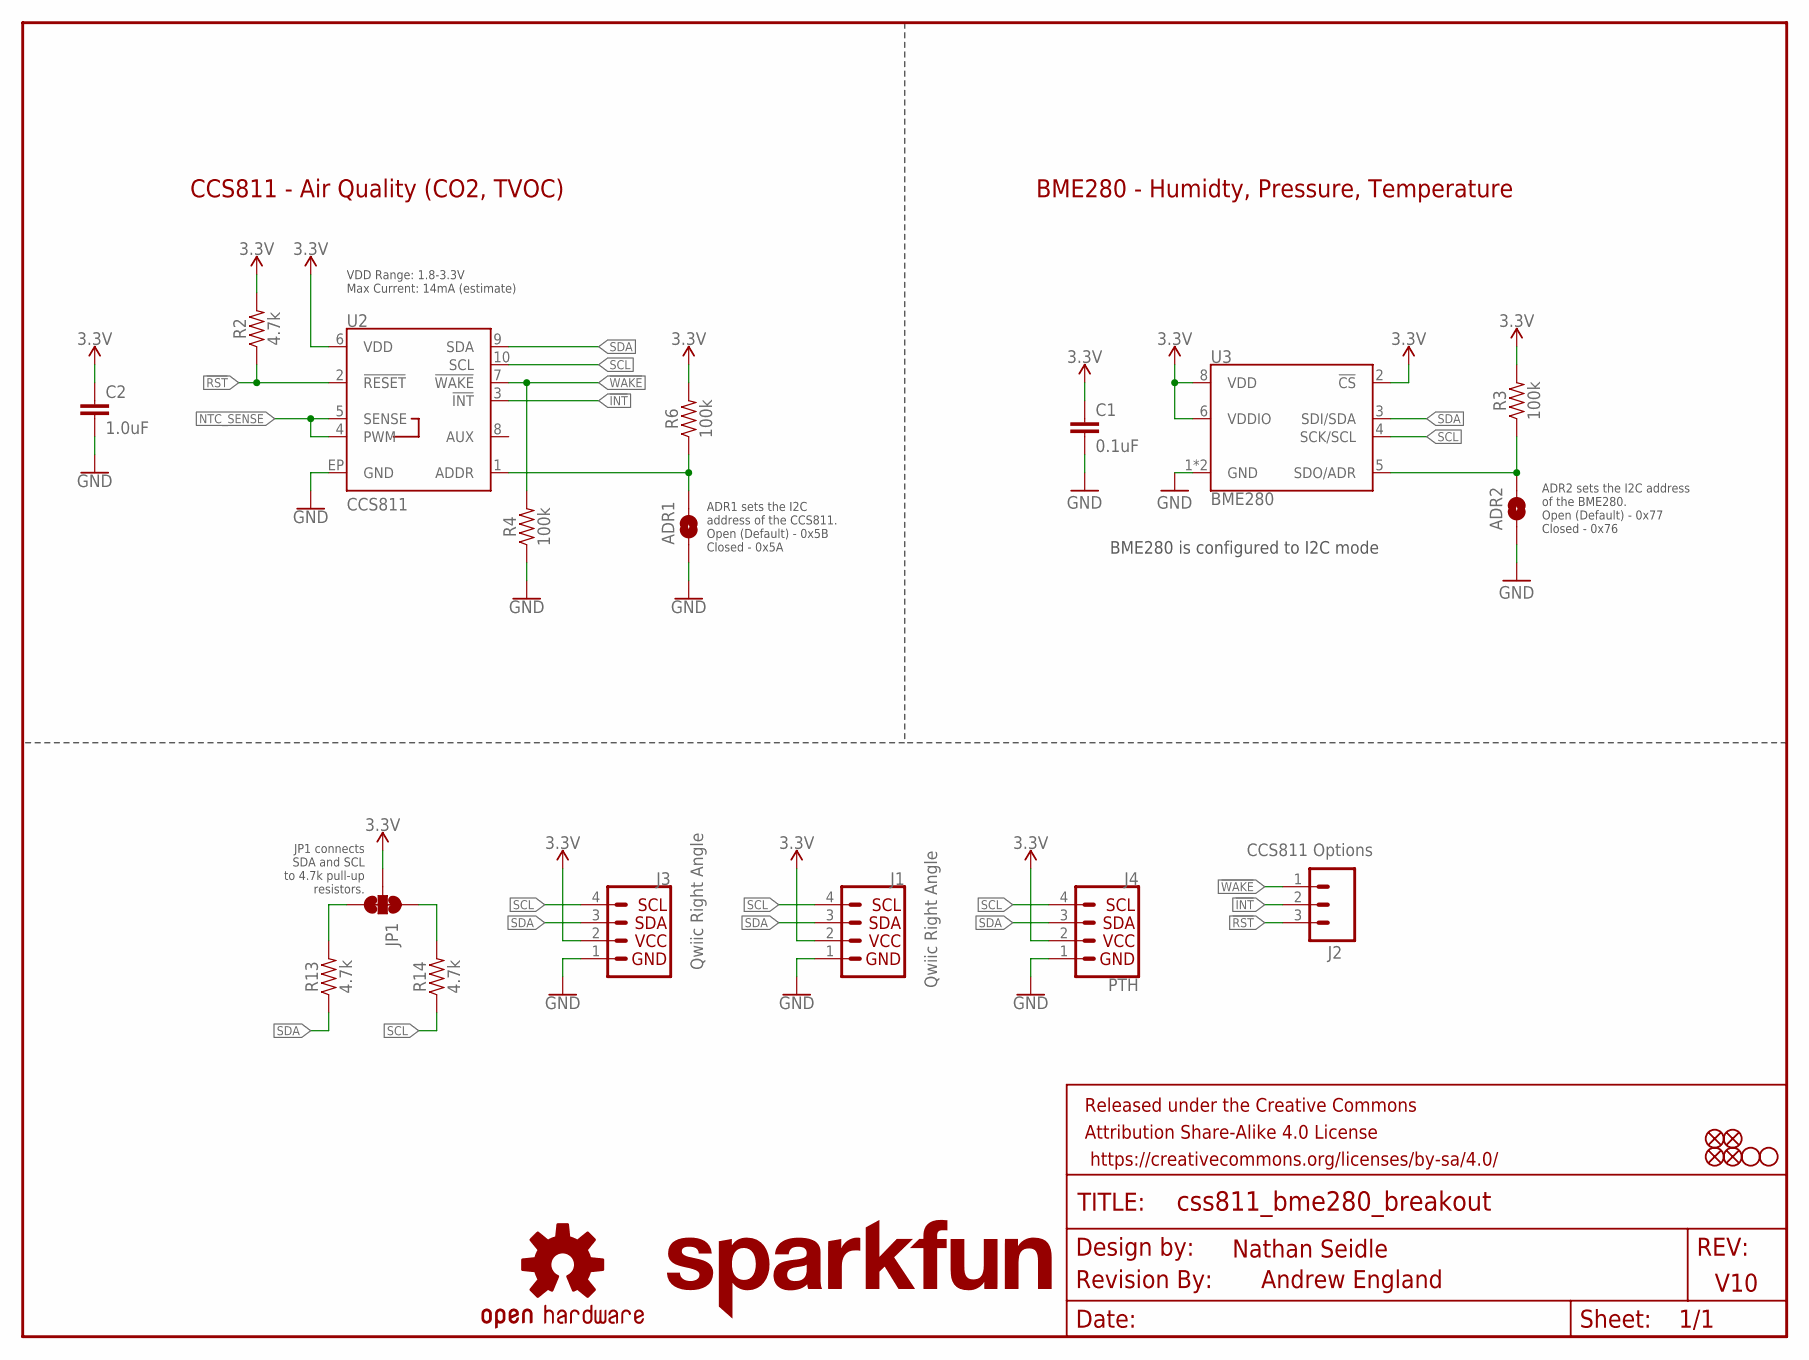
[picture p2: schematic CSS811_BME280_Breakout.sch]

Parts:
ADR1, ADR2: JUMPER-SMT_2_NO_SILK; SMT-JUMPER_2_NO_SILK
C1: 0.1uF; 0603
C2: 1.0uF; 0603
FD1, FD2, FD3, FD4: FIDUCIAL1X2; FIDUCIAL-1X2
FRAME1: FRAME-LETTER; CREATIVE_COMMONS
H2, H4: STAND-OFF
J1, J3: Qwiic Right Angle; 1X04_1MM_RA
J2: CCS811 Options; 1X03_NO_SILK
J4: PTH; 1X04_NO_SILK
JP1: JUMPER-SMT_3_2-NC_TRACE_SILK; SMT-JUMPER_3_2-NC_TRACE_SILK
LOGO1: SFE_LOGO_NAME.1_INCH; SFE_LOGO_NAME_.1
LOGO2: REVISION
LOGO4: OSHW-LOGOS; OSHW-LOGO-S
R2, R13, R14: 4.7k; 0603
R3, R4, R6: 100k; 0603
U2: CCS811; LGA10
U3: BME280; LGA-8-2.5X2.5

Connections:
3.3V: C1.1, C2.1, J1.2, J3.2, J4.2 (VCC), JP1.2, R2.2, R3.2, R6.2, U2.6 (VDD), U3.2 (!CS), U3.6 (VDDIO), U3.8 (VDD)
!INT: J2.2, U2.3 (!INT!)
!RST: J2.3, R2.1, U2.2 (!RESET!)
!WAKE: J2.1, R4.2, U2.7 (!WAKE!)
CCS811_ADDR: ADR1.2, R6.1, U2.1 (ADDR)
GND: ADR1.1, ADR2.1, C1.2, C2.2, J1.1, J3.1, J4.1 (GND), R4.1, U2.EP (GND), U3.1 (GND), U3.7 (GND)
unnamed: JP1.3, R13.2
unnamed: JP1.1, R14.2
NTC_SENSE: U2.4 (PWM), U2.5 (SENSE)
SCL: J1.4, J3.4, J4.4 (SCL), R14.1, U2.10 (SCL), U3.4 (SCK/SCL)
SDA: J1.3, J3.3, J4.3 (SDA), R13.1, U2.9 (SDA), U3.3 (SDI/SDA)
SDO/ADR: ADR2.2, R3.1, U3.5 (SDO/ADR)

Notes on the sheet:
VDD Range: 1.8-3.3V Max Current: 14mA (estimate)
CCS811 - Air Quality (CO2, TVOC)
ADR1 sets the I2C address of the CCS811. Open (Default) - 0x5B Closed - 0x5A
JP1 connects SDA and SCL to 4.7k pull-up resistors.
V10
Nathan Seidle
ADR2 sets the I2C address of the BME280. Open (Default) - 0x77 Closed - 0x76
BME280 is configured to I2C mode
BME280 - Humidty, Pressure, Temperature
Andrew England

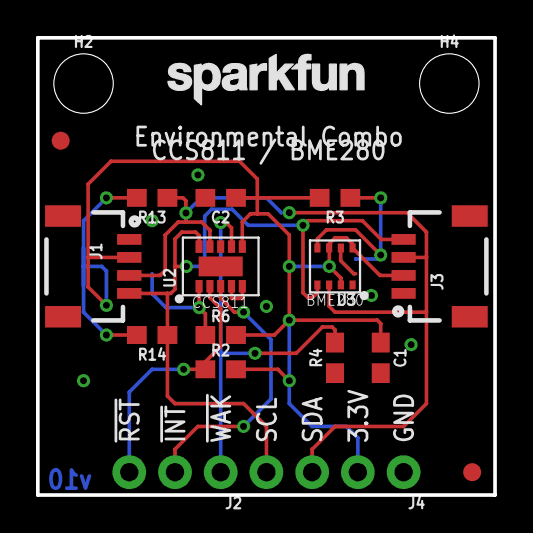
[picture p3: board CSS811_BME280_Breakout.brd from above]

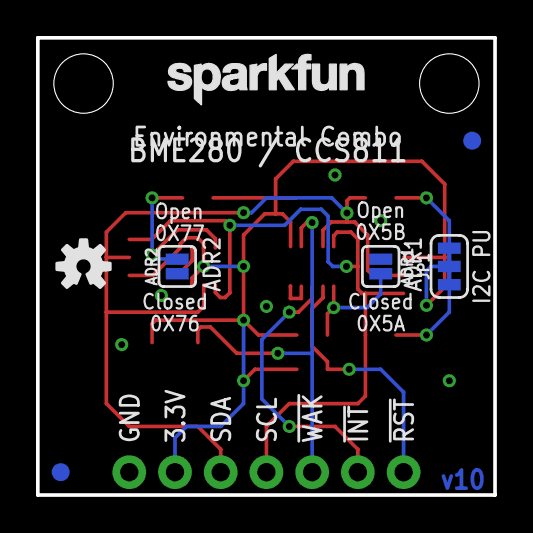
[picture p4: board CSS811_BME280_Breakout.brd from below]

Board: 2 copper layers, 25.4 x 25.4 mm, 28 parts (7 on the bottom side), 12 nets.

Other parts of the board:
LOGO3: SFE_LOGO_NAME.1_INCH; SFE_LOGO_NAME_.1

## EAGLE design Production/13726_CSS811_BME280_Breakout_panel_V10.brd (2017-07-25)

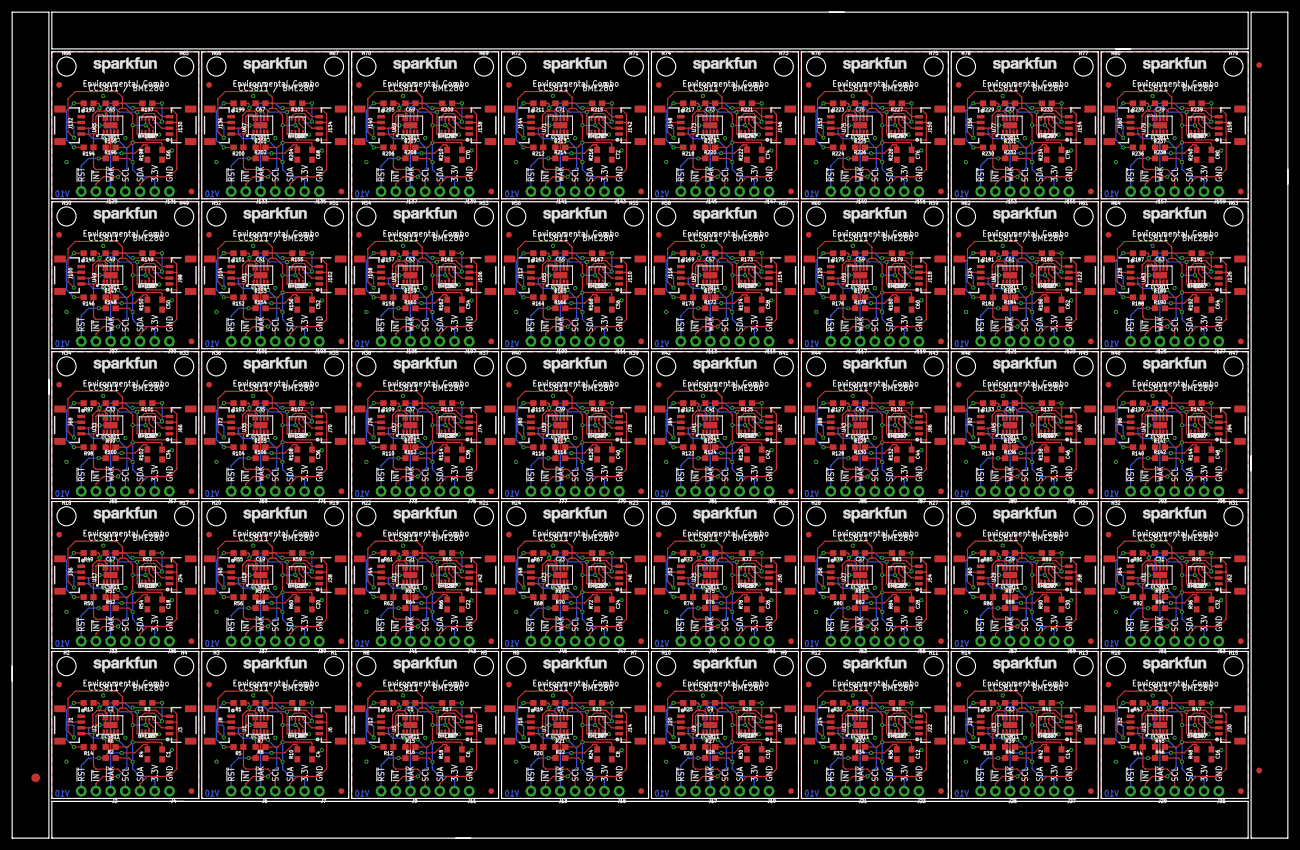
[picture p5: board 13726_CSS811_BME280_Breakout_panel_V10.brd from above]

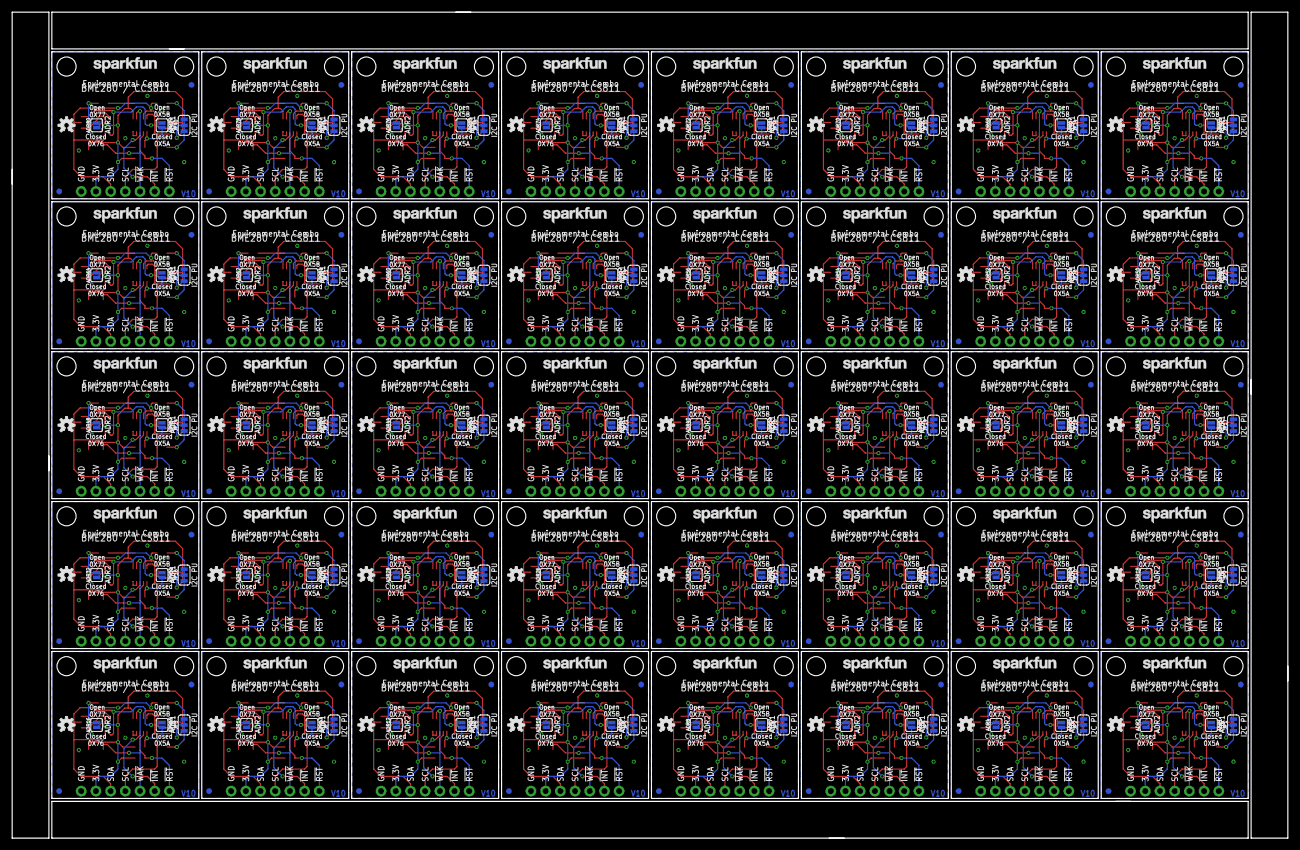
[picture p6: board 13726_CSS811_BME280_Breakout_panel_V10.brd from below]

Board: 2 copper layers, 220.5 x 142.7 mm, 1043 parts (280 on the bottom side), 480 nets.

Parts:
ADR1, ADR2, ADR3, ADR4, ADR5, ADR6, ADR7, ADR8, ADR9, ADR10, ADR11, ADR12, ADR13, ADR14, ADR15, ADR16, ADR17, ADR18, ADR19, ADR20, ADR21, ADR22, ADR23, ADR24, ADR25, ADR26, ADR27, ADR28, ADR29, ADR30, ADR31, ADR32, ADR33, ADR34, ADR35, ADR36, ADR37, ADR38, ADR39, ADR40, ADR41, ADR42, ADR43, ADR44, ADR45, ADR46, ADR47, ADR48, ADR49, ADR50, ADR51, ADR52, ADR53, ADR54, ADR55, ADR56, ADR57, ADR58, ADR59, ADR60, ADR61, ADR62, ADR63, ADR64, ADR65, ADR66, ADR67, ADR68, ADR69, ADR70, ADR71, ADR72, ADR73, ADR74, ADR75, ADR76, ADR77, ADR78, ADR79, ADR80: SMT-JUMPER_2_NO_SILK
C1, C4, C6, C8, C10, C12, C14, C16, C18, C20, C22, C24, C26, C28, C30, C32, C34, C36, C38, C40, C42, C44, C46, C48, C50, C52, C54, C56, C58, C60, C62, C64, C66, C68, C70, C72, C74, C76, C78, C80: 0.1uF; 0603
C2, C3, C5, C7, C9, C11, C13, C15, C17, C19, C21, C23, C25, C27, C29, C31, C33, C35, C37, C39, C41, C43, C45, C47, C49, C51, C53, C55, C57, C59, C61, C63, C65, C67, C69, C71, C73, C75, C77, C79: 1.0uF; 0603
E$1: FIDUCIAL-1.5X3
E$7, E$8: FIDUCIAL-1X2
FD1, FD2, FD3, FD4, FD5, FD6, FD7, FD8, FD9, FD10, FD11, FD12, FD13, FD14, FD15, FD16, FD17, FD18, FD19, FD20, FD21, FD22, FD23, FD24, FD25, FD26, FD27, FD28, FD29, FD30, FD31, FD32, FD33, FD34, FD35, FD36, FD37, FD38, FD39, FD40, FD41, FD42, FD43, FD44, FD45, FD46, FD47, FD48, FD49, FD50, FD51, FD52, FD53, FD54, FD55, FD56, FD57, FD58, FD59, FD60, FD61, FD62, FD63, FD64, FD65, FD66, FD67, FD68, FD69, FD70, FD71, FD72, FD73, FD74, FD75, FD76, FD77, FD78, FD79, FD80, FD81, FD82, FD83, FD84, FD85, FD86, FD87, FD88, FD89, FD90, FD91, FD92, FD93, FD94, FD95, FD96, FD97, FD98, FD99, FD100, FD101, FD102, FD103, FD104, FD105, FD106, FD107, FD108, FD109, FD110, FD111, FD112, FD113, FD114, FD115, FD116, FD117, FD118, FD119, FD120, FD121, FD122, FD123, FD124, FD125, FD126, FD127, FD128, FD129, FD130, FD131, FD132, FD133, FD134, FD135, FD136, FD137, FD138, FD139, FD140, FD141, FD142, FD143, FD144, FD145, FD146, FD147, FD148, FD149, FD150, FD151, FD152, FD153, FD154, FD155, FD156, FD157, FD158, FD159, FD160: FIDUCIAL1X2; FIDUCIAL-1X2
H1, H2, H3, H4, H5, H6, H7, H8, H9, H10, H11, H12, H13, H14, H15, H16, H17, H18, H19, H20, H21, H22, H23, H24, H25, H26, H27, H28, H29, H30, H31, H32, H33, H34, H35, H36, H37, H38, H39, H40, H41, H42, H43, H44, H45, H46, H47, H48, H49, H50, H51, H52, H53, H54, H55, H56, H57, H58, H59, H60, H61, H62, H63, H64, H65, H66, H67, H68, H69, H70, H71, H72, H73, H74, H75, H76, H77, H78, H79, H80: STAND-OFF
J1, J3, J6, J8, J10, J12, J14, J16, J18, J20, J22, J24, J26, J28, J30, J32, J34, J36, J38, J40, J42, J44, J46, J48, J50, J52, J54, J56, J58, J60, J62, J64, J66, J68, J70, J72, J74, J76, J78, J80, J82, J84, J86, J88, J90, J92, J94, J96, J98, J100, J102, J104, J106, J108, J110, J112, J114, J116, J118, J120, J122, J124, J126, J128, J130, J132, J134, J136, J138, J140, J142, J144, J146, J148, J150, J152, J154, J156, J158, J160: Qwiic Right Angle; 1X04_1MM_RA
J2, J5, J9, J13, J17, J21, J25, J29, J33, J37, J41, J45, J49, J53, J57, J61, J65, J69, J73, J77, J81, J85, J89, J93, J97, J101, J105, J109, J113, J117, J121, J125, J129, J133, J137, J141, J145, J149, J153, J157: CCS811 Options; 1X03_NO_SILK
J4, J7, J11, J15, J19, J23, J27, J31, J35, J39, J43, J47, J51, J55, J59, J63, J67, J71, J75, J79, J83, J87, J91, J95, J99, J103, J107, J111, J115, J119, J123, J127, J131, J135, J139, J143, J147, J151, J155, J159: PTH; 1X04_NO_SILK
JP1, JP2, JP3, JP4, JP5, JP6, JP7, JP8, JP9, JP10, JP11, JP12, JP13, JP14, JP15, JP16, JP17, JP18, JP19, JP20, JP21, JP22, JP23, JP24, JP25, JP26, JP27, JP28, JP29, JP30, JP31, JP32, JP33, JP34, JP35, JP36, JP37, JP38, JP39, JP40: SMT-JUMPER_3_2-NC_TRACE_SILK
LOGO1, LOGO3, LOGO5, LOGO6, LOGO8, LOGO9, LOGO11, LOGO12, LOGO14, LOGO15, LOGO17, LOGO18, LOGO20, LOGO21, LOGO23, LOGO24, LOGO26, LOGO27, LOGO29, LOGO30, LOGO32, LOGO33, LOGO35, LOGO36, LOGO38, LOGO39, LOGO41, LOGO42, LOGO44, LOGO45, LOGO47, LOGO48, LOGO50, LOGO51, LOGO53, LOGO54, LOGO56, LOGO57, LOGO59, LOGO60, LOGO62, LOGO63, LOGO65, LOGO66, LOGO68, LOGO69, LOGO71, LOGO72, LOGO74, LOGO75, LOGO77, LOGO78, LOGO80, LOGO81, LOGO83, LOGO84, LOGO86, LOGO87, LOGO89, LOGO90, LOGO92, LOGO93, LOGO95, LOGO96, LOGO98, LOGO99, LOGO101, LOGO102, LOGO104, LOGO105, LOGO107, LOGO108, LOGO110, LOGO111, LOGO113, LOGO114, LOGO116, LOGO117, LOGO119, LOGO120: SFE_LOGO_NAME.1_INCH; SFE_LOGO_NAME_.1
LOGO2, LOGO4, LOGO7, LOGO10, LOGO13, LOGO16, LOGO19, LOGO22, LOGO25, LOGO28, LOGO31, LOGO34, LOGO37, LOGO40, LOGO43, LOGO46, LOGO49, LOGO52, LOGO55, LOGO58, LOGO61, LOGO64, LOGO67, LOGO70, LOGO73, LOGO76, LOGO79, LOGO82, LOGO85, LOGO88, LOGO91, LOGO94, LOGO97, LOGO100, LOGO103, LOGO106, LOGO109, LOGO112, LOGO115, LOGO118: OSHW-LOGOS; OSHW-LOGO-S
R1, R2, R5, R8, R11, R12, R13, R14, R16, R19, R20, R22, R25, R26, R28, R31, R32, R34, R37, R38, R40, R43, R44, R46, R49, R50, R52, R55, R56, R58, R61, R62, R64, R67, R68, R70, R73, R74, R76, R79, R80, R82, R85, R86, R88, R91, R92, R94, R97, R98, R100, R103, R104, R106, R109, R110, R112, R115, R116, R118, R121, R122, R124, R127, R128, R130, R133, R134, R136, R139, R140, R142, R145, R146, R148, R151, R152, R154, R157, R158, R160, R163, R164, R166, R169, R170, R172, R175, R176, R178, R181, R182, R184, R187, R188, R190, R193, R194, R196, R199, R200, R202, R205, R206, R208, R211, R212, R214, R217, R218, R220, R223, R224, R226, R229, R230, R232, R235, R236, R238: 4.7k; 0603
R3, R4, R6, R7, R9, R10, R15, R17, R18, R21, R23, R24, R27, R29, R30, R33, R35, R36, R39, R41, R42, R45, R47, R48, R51, R53, R54, R57, R59, R60, R63, R65, R66, R69, R71, R72, R75, R77, R78, R81, R83, R84, R87, R89, R90, R93, R95, R96, R99, R101, R102, R105, R107, R108, R111, R113, R114, R117, R119, R120, R123, R125, R126, R129, R131, R132, R135, R137, R138, R141, R143, R144, R147, R149, R150, R153, R155, R156, R159, R161, R162, R165, R167, R168, R171, R173, R174, R177, R179, R180, R183, R185, R186, R189, R191, R192, R195, R197, R198, R201, R203, R204, R207, R209, R210, R213, R215, R216, R219, R221, R222, R225, R227, R228, R231, R233, R234, R237, R239, R240: 100k; 0603
U1, U2, U5, U7, U9, U11, U13, U15, U17, U19, U21, U23, U25, U27, U29, U31, U33, U35, U37, U39, U41, U43, U45, U47, U49, U51, U53, U55, U57, U59, U61, U63, U65, U67, U69, U71, U73, U75, U77, U79: CCS811; LGA10
U3, U4, U6, U8, U10, U12, U14, U16, U18, U20, U22, U24, U26, U28, U30, U32, U34, U36, U38, U40, U42, U44, U46, U48, U50, U52, U54, U56, U58, U60, U62, U64, U66, U68, U70, U72, U74, U76, U78, U80: BME280; LGA-8-2.5X2.5

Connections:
3.3V: C1.1, C2.1, J1.2, J3.2, J4.2, JP1.2, R2.2, R3.2, R6.2, U2.6, U3.2, U3.6, U3.8
3.3V1: C3.1, C4.1, J6.2, J7.2, J8.2, JP2.2, R7.2, R8.2, R9.2, U1.6, U4.2, U4.6, U4.8
3.3V2: C5.1, C6.1, J10.2, J11.2, J12.2, JP3.2, R15.2, R16.2, R17.2, U5.6, U6.2, U6.6, U6.8
3.3V3: C7.1, C8.1, J14.2, J15.2, J16.2, JP4.2, R21.2, R22.2, R23.2, U7.6, U8.2, U8.6, U8.8
3.3V4: C9.1, C10.1, J18.2, J19.2, J20.2, JP5.2, R27.2, R28.2, R29.2, U9.6, U10.2, U10.6, U10.8
3.3V5: C11.1, C12.1, J22.2, J23.2, J24.2, JP6.2, R33.2, R34.2, R35.2, U11.6, U12.2, U12.6, U12.8
3.3V6: C13.1, C14.1, J26.2, J27.2, J28.2, JP7.2, R39.2, R40.2, R41.2, U13.6, U14.2, U14.6, U14.8
3.3V7: C15.1, C16.1, J30.2, J31.2, J32.2, JP8.2, R45.2, R46.2, R47.2, U15.6, U16.2, U16.6, U16.8
3.3V8: C17.1, C18.1, J34.2, J35.2, J36.2, JP9.2, R51.2, R52.2, R53.2, U17.6, U18.2, U18.6, U18.8
3.3V9: C19.1, C20.1, J38.2, J39.2, J40.2, JP10.2, R57.2, R58.2, R59.2, U19.6, U20.2, U20.6, U20.8
3.3V10: C21.1, C22.1, J42.2, J43.2, J44.2, JP11.2, R63.2, R64.2, R65.2, U21.6, U22.2, U22.6, U22.8
3.3V11: C23.1, C24.1, J46.2, J47.2, J48.2, JP12.2, R69.2, R70.2, R71.2, U23.6, U24.2, U24.6, U24.8
3.3V12: C25.1, C26.1, J50.2, J51.2, J52.2, JP13.2, R75.2, R76.2, R77.2, U25.6, U26.2, U26.6, U26.8
3.3V13: C27.1, C28.1, J54.2, J55.2, J56.2, JP14.2, R81.2, R82.2, R83.2, U27.6, U28.2, U28.6, U28.8
3.3V14: C29.1, C30.1, J58.2, J59.2, J60.2, JP15.2, R87.2, R88.2, R89.2, U29.6, U30.2, U30.6, U30.8
3.3V15: C31.1, C32.1, J62.2, J63.2, J64.2, JP16.2, R93.2, R94.2, R95.2, U31.6, U32.2, U32.6, U32.8
3.3V16: C33.1, C34.1, J66.2, J67.2, J68.2, JP17.2, R99.2, R100.2, R101.2, U33.6, U34.2, U34.6, U34.8
3.3V17: C35.1, C36.1, J70.2, J71.2, J72.2, JP18.2, R105.2, R106.2, R107.2, U35.6, U36.2, U36.6, U36.8
3.3V18: C37.1, C38.1, J74.2, J75.2, J76.2, JP19.2, R111.2, R112.2, R113.2, U37.6, U38.2, U38.6, U38.8
3.3V19: C39.1, C40.1, J78.2, J79.2, J80.2, JP20.2, R117.2, R118.2, R119.2, U39.6, U40.2, U40.6, U40.8
3.3V20: C41.1, C42.1, J82.2, J83.2, J84.2, JP21.2, R123.2, R124.2, R125.2, U41.6, U42.2, U42.6, U42.8
3.3V21: C43.1, C44.1, J86.2, J87.2, J88.2, JP22.2, R129.2, R130.2, R131.2, U43.6, U44.2, U44.6, U44.8
3.3V22: C45.1, C46.1, J90.2, J91.2, J92.2, JP23.2, R135.2, R136.2, R137.2, U45.6, U46.2, U46.6, U46.8
3.3V23: C47.1, C48.1, J94.2, J95.2, J96.2, JP24.2, R141.2, R142.2, R143.2, U47.6, U48.2, U48.6, U48.8
3.3V24: C49.1, C50.1, J98.2, J99.2, J100.2, JP25.2, R147.2, R148.2, R149.2, U49.6, U50.2, U50.6, U50.8
3.3V25: C51.1, C52.1, J102.2, J103.2, J104.2, JP26.2, R153.2, R154.2, R155.2, U51.6, U52.2, U52.6, U52.8
3.3V26: C53.1, C54.1, J106.2, J107.2, J108.2, JP27.2, R159.2, R160.2, R161.2, U53.6, U54.2, U54.6, U54.8
3.3V27: C55.1, C56.1, J110.2, J111.2, J112.2, JP28.2, R165.2, R166.2, R167.2, U55.6, U56.2, U56.6, U56.8
3.3V28: C57.1, C58.1, J114.2, J115.2, J116.2, JP29.2, R171.2, R172.2, R173.2, U57.6, U58.2, U58.6, U58.8
3.3V29: C59.1, C60.1, J118.2, J119.2, J120.2, JP30.2, R177.2, R178.2, R179.2, U59.6, U60.2, U60.6, U60.8
3.3V30: C61.1, C62.1, J122.2, J123.2, J124.2, JP31.2, R183.2, R184.2, R185.2, U61.6, U62.2, U62.6, U62.8
3.3V31: C63.1, C64.1, J126.2, J127.2, J128.2, JP32.2, R189.2, R190.2, R191.2, U63.6, U64.2, U64.6, U64.8
3.3V32: C65.1, C66.1, J130.2, J131.2, J132.2, JP33.2, R195.2, R196.2, R197.2, U65.6, U66.2, U66.6, U66.8
3.3V33: C67.1, C68.1, J134.2, J135.2, J136.2, JP34.2, R201.2, R202.2, R203.2, U67.6, U68.2, U68.6, U68.8
3.3V34: C69.1, C70.1, J138.2, J139.2, J140.2, JP35.2, R207.2, R208.2, R209.2, U69.6, U70.2, U70.6, U70.8
3.3V35: C71.1, C72.1, J142.2, J143.2, J144.2, JP36.2, R213.2, R214.2, R215.2, U71.6, U72.2, U72.6, U72.8
3.3V36: C73.1, C74.1, J146.2, J147.2, J148.2, JP37.2, R219.2, R220.2, R221.2, U73.6, U74.2, U74.6, U74.8
3.3V37: C75.1, C76.1, J150.2, J151.2, J152.2, JP38.2, R225.2, R226.2, R227.2, U75.6, U76.2, U76.6, U76.8
3.3V38: C77.1, C78.1, J154.2, J155.2, J156.2, JP39.2, R231.2, R232.2, R233.2, U77.6, U78.2, U78.6, U78.8
3.3V39: C79.1, C80.1, J158.2, J159.2, J160.2, JP40.2, R237.2, R238.2, R239.2, U79.6, U80.2, U80.6, U80.8
!INT: J2.2, U2.3
!INT1: J5.2, U1.3
!INT2: J9.2, U5.3
!INT3: J13.2, U7.3
!INT4: J17.2, U9.3
!INT5: J21.2, U11.3
!INT6: J25.2, U13.3
!INT7: J29.2, U15.3
!INT8: J33.2, U17.3
!INT9: J37.2, U19.3
!INT10: J41.2, U21.3
!INT11: J45.2, U23.3
!INT12: J49.2, U25.3
!INT13: J53.2, U27.3
!INT14: J57.2, U29.3
!INT15: J61.2, U31.3
!INT16: J65.2, U33.3
!INT17: J69.2, U35.3
!INT18: J73.2, U37.3
!INT19: J77.2, U39.3
!INT20: J81.2, U41.3
!INT21: J85.2, U43.3
!INT22: J89.2, U45.3
!INT23: J93.2, U47.3
!INT24: J97.2, U49.3
!INT25: J101.2, U51.3
!INT26: J105.2, U53.3
!INT27: J109.2, U55.3
!INT28: J113.2, U57.3
!INT29: J117.2, U59.3
!INT30: J121.2, U61.3
!INT31: J125.2, U63.3
!INT32: J129.2, U65.3
!INT33: J133.2, U67.3
!INT34: J137.2, U69.3
!INT35: J141.2, U71.3
!INT36: J145.2, U73.3
!INT37: J149.2, U75.3
!INT38: J153.2, U77.3
!INT39: J157.2, U79.3
!RST: J2.3, R2.1, U2.2
!RST1: J5.3, R8.1, U1.2
!RST2: J9.3, R16.1, U5.2
!RST3: J13.3, R22.1, U7.2
!RST4: J17.3, R28.1, U9.2
!RST5: J21.3, R34.1, U11.2
!RST6: J25.3, R40.1, U13.2
!RST7: J29.3, R46.1, U15.2
!RST8: J33.3, R52.1, U17.2
!RST9: J37.3, R58.1, U19.2
!RST10: J41.3, R64.1, U21.2
!RST11: J45.3, R70.1, U23.2
!RST12: J49.3, R76.1, U25.2
!RST13: J53.3, R82.1, U27.2
!RST14: J57.3, R88.1, U29.2
!RST15: J61.3, R94.1, U31.2
!RST16: J65.3, R100.1, U33.2
!RST17: J69.3, R106.1, U35.2
!RST18: J73.3, R112.1, U37.2
!RST19: J77.3, R118.1, U39.2
!RST20: J81.3, R124.1, U41.2
!RST21: J85.3, R130.1, U43.2
!RST22: J89.3, R136.1, U45.2
!RST23: J93.3, R142.1, U47.2
!RST24: J97.3, R148.1, U49.2
!RST25: J101.3, R154.1, U51.2
!RST26: J105.3, R160.1, U53.2
!RST27: J109.3, R166.1, U55.2
!RST28: J113.3, R172.1, U57.2
!RST29: J117.3, R178.1, U59.2
!RST30: J121.3, R184.1, U61.2
!RST31: J125.3, R190.1, U63.2
!RST32: J129.3, R196.1, U65.2
!RST33: J133.3, R202.1, U67.2
!RST34: J137.3, R208.1, U69.2
!RST35: J141.3, R214.1, U71.2
!RST36: J145.3, R220.1, U73.2
!RST37: J149.3, R226.1, U75.2
!RST38: J153.3, R232.1, U77.2
!RST39: J157.3, R238.1, U79.2
!WAKE: J2.1, R4.2, U2.7
!WAKE1: J5.1, R10.2, U1.7
!WAKE2: J9.1, R18.2, U5.7
!WAKE3: J13.1, R24.2, U7.7
!WAKE4: J17.1, R30.2, U9.7
!WAKE5: J21.1, R36.2, U11.7
!WAKE6: J25.1, R42.2, U13.7
!WAKE7: J29.1, R48.2, U15.7
!WAKE8: J33.1, R54.2, U17.7
!WAKE9: J37.1, R60.2, U19.7
!WAKE10: J41.1, R66.2, U21.7
!WAKE11: J45.1, R72.2, U23.7
!WAKE12: J49.1, R78.2, U25.7
!WAKE13: J53.1, R84.2, U27.7
!WAKE14: J57.1, R90.2, U29.7
!WAKE15: J61.1, R96.2, U31.7
!WAKE16: J65.1, R102.2, U33.7
!WAKE17: J69.1, R108.2, U35.7
!WAKE18: J73.1, R114.2, U37.7
!WAKE19: J77.1, R120.2, U39.7
!WAKE20: J81.1, R126.2, U41.7
!WAKE21: J85.1, R132.2, U43.7
!WAKE22: J89.1, R138.2, U45.7
!WAKE23: J93.1, R144.2, U47.7
!WAKE24: J97.1, R150.2, U49.7
!WAKE25: J101.1, R156.2, U51.7
!WAKE26: J105.1, R162.2, U53.7
!WAKE27: J109.1, R168.2, U55.7
!WAKE28: J113.1, R174.2, U57.7
!WAKE29: J117.1, R180.2, U59.7
!WAKE30: J121.1, R186.2, U61.7
!WAKE31: J125.1, R192.2, U63.7
!WAKE32: J129.1, R198.2, U65.7
!WAKE33: J133.1, R204.2, U67.7
!WAKE34: J137.1, R210.2, U69.7
!WAKE35: J141.1, R216.2, U71.7
!WAKE36: J145.1, R222.2, U73.7
!WAKE37: J149.1, R228.2, U75.7
!WAKE38: J153.1, R234.2, U77.7
!WAKE39: J157.1, R240.2, U79.7
CCS811_ADDR: ADR1.2, R6.1, U2.1
CCS811_ADDR1: ADR3.2, R7.1, U1.1
CCS811_ADDR2: ADR5.2, R15.1, U5.1
CCS811_ADDR3: ADR7.2, R21.1, U7.1
CCS811_ADDR4: ADR9.2, R27.1, U9.1
CCS811_ADDR5: ADR11.2, R33.1, U11.1
CCS811_ADDR6: ADR13.2, R39.1, U13.1
CCS811_ADDR7: ADR15.2, R45.1, U15.1
CCS811_ADDR8: ADR17.2, R51.1, U17.1
CCS811_ADDR9: ADR19.2, R57.1, U19.1
CCS811_ADDR10: ADR21.2, R63.1, U21.1
CCS811_ADDR11: ADR23.2, R69.1, U23.1
CCS811_ADDR12: ADR25.2, R75.1, U25.1
CCS811_ADDR13: ADR27.2, R81.1, U27.1
CCS811_ADDR14: ADR29.2, R87.1, U29.1
CCS811_ADDR15: ADR31.2, R93.1, U31.1
CCS811_ADDR16: ADR33.2, R99.1, U33.1
CCS811_ADDR17: ADR35.2, R105.1, U35.1
CCS811_ADDR18: ADR37.2, R111.1, U37.1
CCS811_ADDR19: ADR39.2, R117.1, U39.1
CCS811_ADDR20: ADR41.2, R123.1, U41.1
CCS811_ADDR21: ADR43.2, R129.1, U43.1
CCS811_ADDR22: ADR45.2, R135.1, U45.1
CCS811_ADDR23: ADR47.2, R141.1, U47.1
CCS811_ADDR24: ADR49.2, R147.1, U49.1
CCS811_ADDR25: ADR51.2, R153.1, U51.1
CCS811_ADDR26: ADR53.2, R159.1, U53.1
CCS811_ADDR27: ADR55.2, R165.1, U55.1
CCS811_ADDR28: ADR57.2, R171.1, U57.1
CCS811_ADDR29: ADR59.2, R177.1, U59.1
CCS811_ADDR30: ADR61.2, R183.1, U61.1
CCS811_ADDR31: ADR63.2, R189.1, U63.1
CCS811_ADDR32: ADR65.2, R195.1, U65.1
CCS811_ADDR33: ADR67.2, R201.1, U67.1
CCS811_ADDR34: ADR69.2, R207.1, U69.1
CCS811_ADDR35: ADR71.2, R213.1, U71.1
CCS811_ADDR36: ADR73.2, R219.1, U73.1
CCS811_ADDR37: ADR75.2, R225.1, U75.1
CCS811_ADDR38: ADR77.2, R231.1, U77.1
CCS811_ADDR39: ADR79.2, R237.1, U79.1
GND: ADR1.1, ADR2.1, C1.2, C2.2, J1.1, J3.1, J4.1, R4.1, U2.EP, U3.1, U3.7
GND1: ADR3.1, ADR4.1, C3.2, C4.2, J6.1, J7.1, J8.1, R10.1, U1.EP, U4.1, U4.7
GND2: ADR5.1, ADR6.1, C5.2, C6.2, J10.1, J11.1, J12.1, R18.1, U5.EP, U6.1, U6.7
GND3: ADR7.1, ADR8.1, C7.2, C8.2, J14.1, J15.1, J16.1, R24.1, U7.EP, U8.1, U8.7
GND4: ADR9.1, ADR10.1, C9.2, C10.2, J18.1, J19.1, J20.1, R30.1, U9.EP, U10.1, U10.7
GND5: ADR11.1, ADR12.1, C11.2, C12.2, J22.1, J23.1, J24.1, R36.1, U11.EP, U12.1, U12.7
GND6: ADR13.1, ADR14.1, C13.2, C14.2, J26.1, J27.1, J28.1, R42.1, U13.EP, U14.1, U14.7
GND7: ADR15.1, ADR16.1, C15.2, C16.2, J30.1, J31.1, J32.1, R48.1, U15.EP, U16.1, U16.7
GND8: ADR17.1, ADR18.1, C17.2, C18.2, J34.1, J35.1, J36.1, R54.1, U17.EP, U18.1, U18.7
GND9: ADR19.1, ADR20.1, C19.2, C20.2, J38.1, J39.1, J40.1, R60.1, U19.EP, U20.1, U20.7
GND10: ADR21.1, ADR22.1, C21.2, C22.2, J42.1, J43.1, J44.1, R66.1, U21.EP, U22.1, U22.7
GND11: ADR23.1, ADR24.1, C23.2, C24.2, J46.1, J47.1, J48.1, R72.1, U23.EP, U24.1, U24.7
GND12: ADR25.1, ADR26.1, C25.2, C26.2, J50.1, J51.1, J52.1, R78.1, U25.EP, U26.1, U26.7
GND13: ADR27.1, ADR28.1, C27.2, C28.2, J54.1, J55.1, J56.1, R84.1, U27.EP, U28.1, U28.7
GND14: ADR29.1, ADR30.1, C29.2, C30.2, J58.1, J59.1, J60.1, R90.1, U29.EP, U30.1, U30.7
GND15: ADR31.1, ADR32.1, C31.2, C32.2, J62.1, J63.1, J64.1, R96.1, U31.EP, U32.1, U32.7
GND16: ADR33.1, ADR34.1, C33.2, C34.2, J66.1, J67.1, J68.1, R102.1, U33.EP, U34.1, U34.7
GND17: ADR35.1, ADR36.1, C35.2, C36.2, J70.1, J71.1, J72.1, R108.1, U35.EP, U36.1, U36.7
GND18: ADR37.1, ADR38.1, C37.2, C38.2, J74.1, J75.1, J76.1, R114.1, U37.EP, U38.1, U38.7
GND19: ADR39.1, ADR40.1, C39.2, C40.2, J78.1, J79.1, J80.1, R120.1, U39.EP, U40.1, U40.7
GND20: ADR41.1, ADR42.1, C41.2, C42.2, J82.1, J83.1, J84.1, R126.1, U41.EP, U42.1, U42.7
GND21: ADR43.1, ADR44.1, C43.2, C44.2, J86.1, J87.1, J88.1, R132.1, U43.EP, U44.1, U44.7
GND22: ADR45.1, ADR46.1, C45.2, C46.2, J90.1, J91.1, J92.1, R138.1, U45.EP, U46.1, U46.7
GND23: ADR47.1, ADR48.1, C47.2, C48.2, J94.1, J95.1, J96.1, R144.1, U47.EP, U48.1, U48.7
GND24: ADR49.1, ADR50.1, C49.2, C50.2, J98.1, J99.1, J100.1, R150.1, U49.EP, U50.1, U50.7
GND25: ADR51.1, ADR52.1, C51.2, C52.2, J102.1, J103.1, J104.1, R156.1, U51.EP, U52.1, U52.7
GND26: ADR53.1, ADR54.1, C53.2, C54.2, J106.1, J107.1, J108.1, R162.1, U53.EP, U54.1, U54.7
GND27: ADR55.1, ADR56.1, C55.2, C56.2, J110.1, J111.1, J112.1, R168.1, U55.EP, U56.1, U56.7
GND28: ADR57.1, ADR58.1, C57.2, C58.2, J114.1, J115.1, J116.1, R174.1, U57.EP, U58.1, U58.7
GND29: ADR59.1, ADR60.1, C59.2, C60.2, J118.1, J119.1, J120.1, R180.1, U59.EP, U60.1, U60.7
GND30: ADR61.1, ADR62.1, C61.2, C62.2, J122.1, J123.1, J124.1, R186.1, U61.EP, U62.1, U62.7
GND31: ADR63.1, ADR64.1, C63.2, C64.2, J126.1, J127.1, J128.1, R192.1, U63.EP, U64.1, U64.7
GND32: ADR65.1, ADR66.1, C65.2, C66.2, J130.1, J131.1, J132.1, R198.1, U65.EP, U66.1, U66.7
GND33: ADR67.1, ADR68.1, C67.2, C68.2, J134.1, J135.1, J136.1, R204.1, U67.EP, U68.1, U68.7
GND34: ADR69.1, ADR70.1, C69.2, C70.2, J138.1, J139.1, J140.1, R210.1, U69.EP, U70.1, U70.7
GND35: ADR71.1, ADR72.1, C71.2, C72.2, J142.1, J143.1, J144.1, R216.1, U71.EP, U72.1, U72.7
GND36: ADR73.1, ADR74.1, C73.2, C74.2, J146.1, J147.1, J148.1, R222.1, U73.EP, U74.1, U74.7
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

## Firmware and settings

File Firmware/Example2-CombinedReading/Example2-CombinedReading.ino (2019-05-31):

/******************************************************************************
  BME280Compensated.ino
  Marshall Taylor @ SparkFun Electronics
  April 4, 2017
  https://github.com/sparkfun/CCS811_Air_Quality_Breakout
  https://github.com/sparkfun/SparkFun_CCS811_Arduino_Library
  This example uses a BME280 to gather environmental data that is then used
  to compensate the CCS811.
  Hardware Connections (Breakoutboard to Arduino):
  3.3V to 3.3V pin
  GND to GND pin
  SDA to A4
  SCL to A5
  Resources:
  Uses Wire.h for i2c operation
  Development environment specifics:
  Arduino IDE 1.8.1
  This code is released under the [MIT License](http://opensource.org/licenses/MIT).
  Please review the LICENSE.md file included with this example. If you have any questions
  or concerns with licensing, please contact techsupport@sparkfun.com.
  Distributed as-is; no warranty is given.
******************************************************************************/
#include <SparkFunBME280.h>
#include <SparkFunCCS811.h>

#define CCS811_ADDR 0x5B //Default I2C Address
//#define CCS811_ADDR 0x5A //Alternate I2C Address

//Global sensor objects
CCS811 myCCS811(CCS811_ADDR);
BME280 myBME280;

void setup()
{
  Serial.begin(9600);
  Serial.println();
  Serial.println("Apply BME280 data to CCS811 for compensation.");
  
  Wire.begin();//initialize I2C bus
  
  //This begins the CCS811 sensor and prints error status of .begin()
  CCS811Core::status returnCode = myCCS811.begin();
  if (returnCode != CCS811Core::SENSOR_SUCCESS)
  {
    Serial.println("Problem with CCS811");
    printDriverError(returnCode);
  }
  else
  {
    Serial.println("CCS811 online");
  }

  
  //Initialize BME280
  //For I2C, enable the following and disable the SPI section
  myBME280.settings.commInterface = I2C_MODE;
  myBME280.settings.I2CAddress = 0x77;
  myBME280.settings.runMode = 3; //Normal mode
  myBME280.settings.tStandby = 0;
  myBME280.settings.filter = 4;
  myBME280.settings.tempOverSample = 5;
  myBME280.settings.pressOverSample = 5;
  myBME280.settings.humidOverSample = 5;

  //Calling .begin() causes the settings to be loaded
  delay(10);  //Make sure sensor had enough time to turn on. BME280 requires 2ms to start up.
  byte id = myBME280.begin(); //Returns ID of 0x60 if successful
  if (id != 0x60)
  {
    Serial.println("Problem with BME280");
  }
  else
  {
    Serial.println("BME280 online");
  }


}
//---------------------------------------------------------------
void loop()
{
  //Check to see if data is available
  if (myCCS811.dataAvailable())
  {
    //Calling this function updates the global tVOC and eCO2 variables
    myCCS811.readAlgorithmResults();
    //printData fetches the values of tVOC and eCO2
    printData();

    float BMEtempC = myBME280.readTempC();
    float BMEhumid = myBME280.readFloatHumidity();

    Serial.print("Applying new values (deg C, %): ");
    Serial.print(BMEtempC);
    Serial.print(",");
    Serial.println(BMEhumid);
    Serial.println();

    //This sends the temperature data to the CCS811
    myCCS811.setEnvironmentalData(BMEhumid, BMEtempC);
  }
  else if (myCCS811.checkForStatusError())
  {
    Serial.println(myCCS811.getErrorRegister()); //Prints whatever CSS811 error flags are detected
  }

  delay(2000); //Wait for next reading
}

//---------------------------------------------------------------
void printData()
{
  Serial.print(" CO2[");
  Serial.print(myCCS811.getCO2());
  Serial.print("]ppm");

  Serial.print(" TVOC[");
  Serial.print(myCCS811.getTVOC());
  Serial.print("]ppb");

  Serial.print(" temp[");
  Serial.print(myBME280.readTempC(), 1);
  Serial.print("]C");

  //Serial.print(" temp[");
  //Serial.print(myBME280.readTempF(), 1);
  //Serial.print("]F");

  Serial.print(" pressure[");
  Serial.print(myBME280.readFloatPressure(), 2);
  Serial.print("]Pa");

  //Serial.print(" pressure[");
  //Serial.print((myBME280.readFloatPressure() * 0.0002953), 2);
  //Serial.print("]InHg");

  //Serial.print("altitude[");
  //Serial.print(myBME280.readFloatAltitudeMeters(), 2);
  //Serial.print("]m");

  //Serial.print("altitude[");
  //Serial.print(myBME280.readFloatAltitudeFeet(), 2);
  //Serial.print("]ft");

  Serial.print(" humidity[");
  Serial.print(myBME280.readFloatHumidity(), 0);
  Serial.print("]%");

  Serial.println();
}

//printDriverError decodes the CCS811Core::status type and prints the
//type of error to the serial terminal.
//
//Save the return value of any function of type CCS811Core::status, then pass
//to this function to see what the output was.
void printDriverError( CCS811Core::status errorCode )
{
  switch ( errorCode )
  {
    case CCS811Core::SENSOR_SUCCESS:
      Serial.print("SUCCESS");
      break;
    case CCS811Core::SENSOR_ID_ERROR:
      Serial.print("ID_ERROR");
      break;
    case CCS811Core::SENSOR_I2C_ERROR:
      Serial.print("I2C_ERROR");
      break;
    case CCS811Core::SENSOR_INTERNAL_ERROR:
      Serial.print("INTERNAL_ERROR");
      break;
    case CCS811Core::SENSOR_GENERIC_ERROR:
      Serial.print("GENERIC_ERROR");
      break;
    default:
      Serial.print("Unspecified error.");
  }
}

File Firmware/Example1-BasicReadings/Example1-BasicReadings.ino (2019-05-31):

/*
  Read both CCS811 and BME280 sensors at same time
  By: Nathan Seidle
  SparkFun Electronics
  Date: April 6th, 2017
  License: This code is public domain but you buy me a beer if you use this and we meet someday (Beerware license).

  Works with SparkFun combo board https://www.sparkfun.com/products/14241
  Enjoy this code? Buy a board and help support SparkFun! 
  
  Let's read both sensors at the same time!
  Outputs CO2, TVOC, temperature, humidty, and pressure.
  
  Hardware Connections (Breakoutboard to Arduino):
  Attach a Qwiic Shield to your RedBoard, Photon, or ESP32.
  Plug the Qwiic Air Quality Combo board into one of the connectors
  Serial.print it out at 9600 baud to serial monitor.

*/

#include <Wire.h>
#include "SparkFunBME280.h" //Library for BME280 from library manager or https://github.com/sparkfun/SparkFun_BME280_Arduino_Library
#include "SparkFunCCS811.h"

#define CCS811_ADDR 0x5B

CCS811 myCCS811(CCS811_ADDR);
BME280 myBME280; //Global sensor object for BME280

//Global variables obtained from the two sensors
unsigned int tVOC = 0;
unsigned int CO2 = 0;
float tempf = 0;
float humidity = 0;
float pressureInHg = 0;

void setup()
{
  Serial.begin(9600);
  Serial.println("CCS811+BME280 Read Example");
  
  Wire.begin();//initialize I2C bus
  
  CCS811Core::status returnCode = myCCS811.begin();
  if (returnCode != CCS811Core::SENSOR_SUCCESS)
  {
    Serial.println("Problem with CCS811");
    printDriverError(returnCode);
  }
  else
  {
    Serial.println("CCS811 online");
  }

  //Setup the BME280 for basic readings
  myBME280.settings.commInterface = I2C_MODE;
  myBME280.settings.I2CAddress = 0x77;
  myBME280.settings.runMode = 3; //  3, Normal mode
  myBME280.settings.tStandby = 0; //  0, 0.5ms
  myBME280.settings.filter = 0; //  0, filter off
  myBME280.settings.tempOverSample = 1;
  myBME280.settings.pressOverSample = 1;
  myBME280.settings.humidOverSample = 1;

  delay(10); //Give BME280 time to come on
  //Calling .begin() causes the settings to be loaded
  byte id = myBME280.begin(); //Returns ID of 0x60 if successful
  if (id != 0x60)
  {
    Serial.println("Problem with BME280");
  }
  else
  {
    Serial.println("BME280 online");
  }
}

void loop()
{
  if (myCCS811.dataAvailable()) //Check to see if CCS811 has new data (it's the slowest sensor)
  {
    myCCS811.readAlgorithmResults(); //Read latest from CCS811 and update tVOC and CO2 variables
    //getWeather(); //Get latest humidity/pressure/temp data from BME280
    printData(); //Pretty print all the data
  }
  else if (myCCS811.checkForStatusError()) //Check to see if CCS811 has thrown an error
  {
    Serial.println(myCCS811.getErrorRegister()); //Prints whatever CSS811 error flags are detected
  }

  delay(2000); //Wait for next reading
}

//Print CO2, TVOC, Humidity, Pressure and Temp
void printData()
{
  Serial.print(" CO2[");
  Serial.print(myCCS811.getCO2());
  Serial.print("]ppm");

  Serial.print(" TVOC[");
  Serial.print(myCCS811.getTVOC());
  Serial.print("]ppb");

  Serial.print(" temp[");
  Serial.print(myBME280.readTempC(), 1);
  Serial.print("]C");

  //Serial.print(" temp[");
  //Serial.print(myBME280.readTempF(), 1);
  //Serial.print("]F");

  Serial.print(" pressure[");
  Serial.print(myBME280.readFloatPressure(), 2);
  Serial.print("]Pa");

  //Serial.print(" pressure[");
  //Serial.print((myBME280.readFloatPressure() * 0.0002953), 2);
  //Serial.print("]InHg");

  //Serial.print("altitude[");
  //Serial.print(myBME280.readFloatAltitudeMeters(), 2);
  //Serial.print("]m");

  //Serial.print("altitude[");
  //Serial.print(myBME280.readFloatAltitudeFeet(), 2);
  //Serial.print("]ft");

  Serial.print(" humidity[");
  Serial.print(myBME280.readFloatHumidity(), 0);
  Serial.print("]%");

  Serial.println();
}

void printDriverError( CCS811Core::status errorCode )
{
  switch ( errorCode )
  {
    case CCS811Core::SENSOR_SUCCESS:
      Serial.print("SUCCESS");
      break;
    case CCS811Core::SENSOR_ID_ERROR:
      Serial.print("ID_ERROR");
      break;
    case CCS811Core::SENSOR_I2C_ERROR:
      Serial.print("I2C_ERROR");
      break;
    case CCS811Core::SENSOR_INTERNAL_ERROR:
      Serial.print("INTERNAL_ERROR");
      break;
    case CCS811Core::SENSOR_GENERIC_ERROR:
      Serial.print("GENERIC_ERROR");
      break;
    default:
      Serial.print("Unspecified error.");
  }
}

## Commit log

2017-06-16 added eagle files
    [CSS811_BME280_Breakout.brd, CSS811_BME280_Breakout.sch]
2017-06-20 Updated file structure to match SFE repo
    [CSS811_BME280_Breakout.brd, CSS811_BME280_Breakout.sch]
2017-06-20 Updated parts to fit with SFE library
    [CSS811_BME280_Breakout.brd, CSS811_BME280_Breakout.sch]
2017-07-05 Pre design review changes
    [Board_Design_Checklist.xls, Board_Design_Checklist_Environmental Combo Board_V01.xls, CSS811_BME280_Breakout.brd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]
2017-07-05 Added Dimensions
    [CSS811_BME280_Breakout.brd, CSS811_BME280_Breakout.sch]
2017-07-06 Added fiducials to bottom of board
    [CSS811_BME280_Breakout.brd, CSS811_BME280_Breakout.sch]
2017-07-06 Post design review aesthetic changes
    [CSS811_BME280_Breakout.brd, CSS811_BME280_Breakout.sch]
2017-07-07 updated silk for Reds
    [CSS811_BME280_Breakout.brd, CSS811_BME280_Breakout.sch]
2017-07-18 added units
    [CSS811_BME280_Breakout.brd]
2017-07-25 Changed V to v
    [CSS811_BME280_Breakout.brd]
2017-08-23 moved engineering checklist
    [Board_Design_Checklist.xls, Board_Design_Checklist_Environmental Combo Board_V01.xls]
2017-09-07 Squashed 'Libraries/Arduino/' content from commit d0663f3
    git-subtree-dir: Libraries/Arduino
    git-subtree-split: d0663f31b8e9cb3536c5eda6ba2fe3e3023c2f0a
2017-09-07 Squashed 'Libraries/Arduino/' content from commit 9a2a24d
    git-subtree-split: 9a2a24d2b25db1f430d7b6b9ff62c388d72c60e1
    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

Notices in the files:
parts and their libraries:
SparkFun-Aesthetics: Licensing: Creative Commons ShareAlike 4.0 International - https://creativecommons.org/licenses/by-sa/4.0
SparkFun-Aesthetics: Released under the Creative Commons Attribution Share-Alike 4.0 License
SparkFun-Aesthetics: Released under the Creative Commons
